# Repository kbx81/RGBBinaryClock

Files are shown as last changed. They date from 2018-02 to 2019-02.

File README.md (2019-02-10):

# kbx's RGB Binary Clock

RGB Binary Clock project files - PCB and source

_It's probably more than what you're thinking..._

## Another binary clock? Why?

I have to start by giving credit where credit is due. The
 [Boldport Club](http://boldport.club), over the last couple of years, has
 motivated me to dwell back into the world of electronics, at least as a
 hobbyist. Both the kits themselves and the other members in the club are
 amazing and helped inspire me to make something...so I began working on this
 project. Some inspiration is taken from
 [Touchy, BPC Project #7](https://www.boldport.com/products/touchy); this kit
 enabled me to learn more about and actually experiment with capacitive touch.
 It was clear early on that this would be a nice touch (pun intended) to add to
 this project; visually, it is cleaner, it reduces the number of parts and, as a
 result, it reduces the cost.

That said, the world probably doesn't need another (binary) clock. There are
 plenty of them--all different shapes and sizes--so why build another one?

This project was started with two main goals in mind: I wanted a "simple"
 project I could use to help me get back into the world of electronics. The
 second goal I had in mind was to build up my comfort level with C and C++ -- I
 knew the language(s) but was never terribly comfortable with them. Building
 this helped me to achieve both of those goals and then some -- and I am quite
 happy with the result!

_But why a clock?_

It's fun to make LEDs blink. It's fun to play with microcontrollers. It's fun
 to build stuff. But a blinking LED or two or three isn't very meaningful. Nor
 is a nice microcontroller that just toggles a GPIO pin. If you're going to
 build something, why not make it at least modestly useful? And why not build it
 in a unique way that's neat to look at and/or watch?

The idea for this came from an old electronics kit I put together probably
 around twenty or so years ago (and it still works today!). I liked the kit but
 it was somehow lacking. Probably the most obvious problem was that, in a dark
 bedroom, the display was too bright. It was a simple, 12-hour-only binary
 clock, built on 4000-series CMOS logic. Now, there's nothing wrong with that,
 but...it's 2018 now. Let's take it up a notch or ten.

## How do you take a binary clock up a notch (or ten)?

First, you can add some color. A lot of color. In fact, you can pick the colors
 you want it to use...up to eight times over. This binary clock has the ability
 to gradually shift colors over the course of each day. Bits can even fade in
 and out as they change. It's all about the eye candy in this regard.

Second, it can do more than just tell the time -- it'll tell you the date and
 temperature, too! There is even a timer/counter mode. What's more, you can
 choose the format for it all: the clock can display in a 12 or 24 hour format,
 the temperature can display in degrees Celsius or degrees Fahrenheit, and (most
 importantly) it can display all of these values in either binary-coded decimal
 (BCD) or good old-fashioned binary. You get to choose the formats you prefer
 and they can be changed easily at any time.

Next, the display brightness issue had to be addressed -- it has a
 phototransistor which is used to determine the amount of ambient light around
 it and the display will dim as the light level around it diminishes. This is
 great if you want to keep it near you at night while you sleep.

Another cool bit is that it uses capacitive sense touch keys for buttons; the
 kit it is based on had mechanical, fixed-function buttons. If you haven't seen
 or used capsense technology before, you'll find it's pretty cool and adds a
 little extra uniqueness to the clock, too.

A CR2032 coin-cell battery back-up can be installed to keep the time valid in
 the event that the board loses power. Version 4 of the hardware also includes a
 super capacitor, eliminating the need for the battery; even so, both can be
 installed, adding flexibility to the build.

Finally--and one could argue that no clock is complete without one--it has an
 alarm! The alarm can be set to beep at any of the eight times the user sets.
 There is also an hourly chime that one can enable which will beep out each hour
 in binary using high and/or low pitch tones...so you can hear the time when
 you're in another room! The display can be configured to blink when an alarm
 occurs. Version 4 of the clock also includes extra pin headers, some pins of
 which can be used as inputs to trigger the alarm from an external device.

## Great, but what makes it tick?

The "brain" is an STM32F072 microcontroller. This MCU alone has everything
 that's necessary to have a functional time clock -- even a temperature sensor
 as a bonus. Still, it might not be quite as accurate as some of us would like.
 For those folks, there are footprints for some additional ICs to improve the
 accuracy of the time and/or temperature sensing.

Version 2 boards have footprints for I2C devices:
* A Maxim DS3231
* An LM75 (or compatible)
* A Microchip MCP9808

Version 3+ boards have footprints for SPI devices:
* A Maxim DS3234
* An LM74
* A Maxim DS1722

Why footprints for both temperature sensors and the RTCs? The DS323x is somewhat
 expensive and it's possible that one might want more accurate temperature
 sensing abilities but isn't as concerned with the accuracy of the clock. It
 should be noted that the DS323x devices have temperature sensors built in and
 the application will use this sensor if a DS323x is installed but one of the
 other external temperature sensors is not.

Beyond the MCU itself, the board has 25 RGB LEDs on it; 24 of them form the main
 display and they are connected to TLC5947 (pre-v4) or TLC5951 (v4+)
 constant-current PWM drivers. The MCU uses its SPI1 to communicate with these
 drivers. The remaining RGB LED is used as a "status" LED and it is connected
 (through FET drivers) to GPIO pins on the MCU. These pins double as timer
 output channels, meaning they can also generate a PWM signal, enabling the
 dimming of the status LED elements, as well.

The beeper is connected (also through a FET driver) to yet another GPIO pin
 that doubles as a timer output channel; this enables the beeper to generate a
 wide range of tones or even play a tune!

The phototransistor is connected to the MCU's ADC channel zero.

Two USARTs are exposed via pin headers on the right side of the board: USART1
 is brought out on a standard six pin header as is commonly found on many
 devices while USART2 is connected to an RS-485 line driver enabling
 communication on an RS-485 bus. Through this interface, the application is able
 to receive a DMX-512 signal so the LEDs can each be individually controlled
 from an entertainment lighting console (or other application that speaks this
 protocol), enabling another whole realm of possibilities...

## How do I get or build one?

In this repository you'll find everything needed to put one together. It is
 divided into two major parts: hardware and software (source). The `hardware`
 directory contains the [KiCad](http://kicad.org) project files used to create
 the printed circuit board. The `src` directory contains the source code needed
 to compile and run the application on the microcontroller. It is built on top
 of [libopencm3](http://libopencm3.org). Finally, then `bin` directory contains
 compiled binary files you may flash directly onto the microcontroller...great
 for folks who want to solder something together but don't want to be bothered
 with compiling code!

Additional details regarding the hardware and software can be found in the
 `README.md` files located in each respective directory.

 **That's all for now...thanks for visiting!**

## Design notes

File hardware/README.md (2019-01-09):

# kbx's RGB Binary Clock

RGB Binary Clock PCB project files for KiCad (v4/v5)

## How do I get PCBs made for this?

Detailing the process is a bit outside of what I plan to discuss here. There are
 plenty of resources out around the web already that will do a better job of
 explaining this process than I can. That said, there's not much to it -- the
 files you need are here and all you need to do (more or less) is upload them
 to your PCB fabricator of choice and, after a few days, they'll ship them
 to you. I've used [OSHPark](http://oshpark.com) for the prototypes and I can
 assure you that they turn out fantastic (purple) boards.

As the vast majority of the components on this board are surface-mount parts,
 hot air is a fun approach for soldering it all together. If you go this route
 (and especially if you plan to build more than one of them), you'll likely want
 to have a stencil made to help with the placement of solder paste onto the
 board. I've used [OSHStencils](http://oshstencils.com) for this and they are
 very quick and do a wonderful job.

**Important**: The TLC5947 and TLC5951 LED driver ICs have a thermal relief (aka
 exposed) pad on their underside; this will not be possible to solder without a
 hot air soldering station or reflow oven. At low current/intensity levels, this
 shouldn't be a problem, but if you want your LEDs to be really bright, this
 could present an issue as the drivers will overheat quickly. Be careful!

## If I get boards made, how do I build it?

All the components are listed in the KiCad project files here; one can also find
 a bill of materials file named `kbxBinaryClock.bom.vX.csv` containing this
 list. For "unusual" parts (things that aren't resistors or capacitors) I've
 noted a suggested part number that should serve as a point of reference to help
 you find your own.

Before you order parts, be sure to read through the build notes below!

Once you have your boards and parts, there are at least a couple of different
 ways you can build the clock. Below are build notes.

## Build notes

### Before you begin...

...you need to determine:
1. Which version of the clock will you build? The answer should be "version 4"
 unless there is a specific reason you want/need an earlier version.
1. What will your time source be -- the STM32's RTC or the DS323x? The DS323x
 will provide the best accuracy. That said, these ICs add approximately $10 USD
 to the cost of the device. If you're purchasing them, be sure you're ordering
 the one that matches the version of the hardware you're planning on building!
1. What temperature sensor will you use -- the STM32's internal sensor, the
 DS323x's sensor, or a dedicated sensor? The DS1621/LM75/MCP9804/DS1722/LM74
 dedicated sensors will provide the best accuracy; however, if one of these ICs
 is not installed but a DS323x *is* installed, the app will use the DS323x's
 sensor. Note that, while the PCBs have footprints for more than one temperature
 sensor, only **one** of them may be installed at a time.
1. Solder-bridge/jumper settings. These are hardware version specific but *must*
 be set properly before you begin using the clock. More details are below...but
 don't forget about these!

Once you've settled on the items above, read on (below) for more detail and
 specifics regarding the build.

### Build details

#### External RTC:

The external RTC--the DS3231 (hardware version 2.x) or the DS3234 (hardware
 version 3.x+)--adds a level of precision to the clock that is likely difficult
 to achieve with the STM32's internal RTC alone. These RTC ICs are designed to
 drift less than two minutes _per year_. It's possible that your STM32 hardware
 could end up being this accurate, but it's more likely that it will not be.
 Install this IC if you want a clock that is as accurate as is reasonably
 possible. Note that this IC also has a built-in temperature sensor (that's part
 of how it maintains its precision) that the application will use if it is
 installed and the other external temperature sensor (below) is _not_ installed.

If you install a DS3231/DS3234 on your clock, **do not install**:
 - Hardware v2.x: `C6`, `R8`
 - Hardware v3.x: `C6`, `R19`
 - Hardware v4.x: `C5`, `R3`

#### External temperature sensors:
**U7 and U8 (all hardware versions)**

A challenge with using the STM32's internal temperature sensor is that the
 sensor typically reads a few degrees higher than the temperature around the
 MCU itself. This is because the die, where the sensor is located, is usually
 just a little bit warmer then the package around it. An easy workaround is to
 just subtract a few degrees from the reading -- hence the calibration item
 you'll find in the application's menu structure. It works, but it requires
 someone to tweak it as each chip is likely to be a little different. Naturally,
 this takes away from its accuracy.

Installing an external temperature sensor is a great solution to this problem.
 The application will prefer an external sensor if one is installed; it first
 prefers one of the dedicated temperature sensors. If not installed, it will try
 to use the sensor integrated into the DS323x, should one be installed. If these
 all fail, it will use the STM32's internal sensor as a last resort.

**IMPORTANT NOTE: the PCBs (all hardware versions) have footprints for two
 external temperature sensor ICs. ONLY INSTALL ONE of them. DO NOT INSTALL
 BOTH.** If you install both, neither of them will work and you may cause damage
 to them or to other ICs on the board.

#### RS-485 transceiver:
**U9** (hardware v2.x and v3.x)\
**U6** (hardware v4.x)

This part will enable the the second USART in the STM32 MCU to be used to
 communicate on an RS-485 bus. The original intention for this feature was to
 enable the device to receive a DMX-512 signal from an entertainment lighting
 console. With some development, it could also be used (for example) to
 synchronize a number of clocks with each other. This interface is more of a toy
 and has no impact on how the clock itself will function. You'll likely want to
 leave it off of the board unless you have a specific plan to use it for
 something.

#### Buzzer/beeper components:
**BZ1, D1, Q1, R1** (hardware v2.x and v3.x)\
**BZ1, D2, Q2, R19** (hardware v4.x)

If you don't want your clock to be able to make any noise at all, it is safe to
 leave these parts off of your board. It'll be sad, but it'll work just fine.

#### Current drive control components:
**Q6 through Q11, R21 through R24, R26 through R29, R31 through R34,
 R36 and R37** (hardware v2.x)\
**Q6 through Q11, R20 through R23, R25 through R28, R30 through R33,
 R35 and R36** (hardware v3.x)\
(Not applicable to hardware v4.x)

These parts enable some software control over the constant-current mechanism in
 the TLC5947 PWM drivers. They enable, in a sense, a "master dimmer" control
 over the display as a whole. Their state can be defined through one of the menu
 options within the application. While not implemented just yet, future software
 versions might exercise them automatically, such as when the ambient light
 level changes.

#### Status LED components:
**LED25, LED26, Q2 through Q4, R2 through R7** (hardware v2.x and v3.x)\
**LED25, LED26, Q3 through Q5, R20 through R22, R25 through R27** (hardware v4.x)

The status LED is not typically used during normal operation, however it can be
 enabled as an AM/PM indicator if/when the clock is set in 12-hour mode. It can
 also provide troubleshooting information if your clock doesn't seem to be
 working. That said, it's not necessary unless you like LEDs as much as I do.

#### Reset/Boot buttons:

The reset and boot buttons are of course not required, but it is convenient if
 you plan to do any development with this platform on your own.

### Other requirements

#### 32.768 kHz crystal installation and connection:

A footprint for a 32.768 kHz crystal exists on all of the PCBs. It is used to
 drive the STM32's internal RTC mechanism. This crystal is particularly
 important if the DS323x IC is **not** installed; in this case, it must be
 connected to the MCU by creating a solder bridge across the appropriate two
 pads on `SB1`. Failure to do so--and if the DS323x is not installed--means the
 clock won't run (although things otherwise may seem to work).

If the DS323x **is** installed, `SB1` may be bridged so as to connect the
 DS323x's 32.768 kHz signal output to the STM32's OSC32 input. This is not
 required but it is recommended so that this MCU input isn't left floating. In
 addition, if `SB1` is bridged in this manner, the 32.768 kHz crystal (and its
 drive capacitors) should **not** be installed.

#### Phototransistor series resistors:
 **Q5, RV1, R9 and R10** (hardware v2.x)\
 **Q5, RV1, R8 and R9** (hardware v3.x)\
 **Q1, RV1, R4 and R5** (hardware v4.x)

The phototransistor enables the application to determine the amount of ambient
 light around the clock so it can adjust the overall display intensity
 accordingly. There is a variable resistor in series with a fixed resistor which
 allows some manual adjustment over the sensitivity of this mechanism. There is
 also a single fixed resistor in parallel with this configuration. It is not
 necessary to install all of these, however it won't hurt anything if you do.
 If the specified phototransistor is used, a single 100K to 150K resistor
 installed on the larger component number's (`R5`, `R9` or `R10`, depending on
 your hardware version) pads will probably work well.

#### Status LED:

If installing a status LED, install only LED25 **or** LED26. Do not install
 both.

### Solder Bridge Jumpers

#### 32.768 kHz Oscillator jumper
**SB1**

This jumper determines if the 32.768 kHz oscillator or the DS323x's 32.768 kHz
 output pin is connected to the STM32's OSC32_IN pin. If a DS323x is **not**
 installed on the board, it must be bridged so that the crystal's pin is
 connected to the OSC32_IN pin. Otherwise, it's best to bridge it to the
 DS323x's 32.768 kHz output pin. It can be determined with a close look at the
 PCB which position is which.

#### Reset Supervisor jumper
**SB2** (hardware v2.x and v3.x)\
**SB4** (hardware v4.x)

This jumper determines if the DS323x's reset supervisor output pin is connected
 to the STM32's NRST (not-reset) pin. This should be connected if the DS323x is
 installed, however it sometimes causes issues with flashing the MCU. If you
 installed a DS323x and are having difficulty flashing the MCU, try
 disconnecting this jumper until the flashing process is complete. Don't forget
 to reconnect it, though!

#### USART 1/USB VBUS jumpers
**SB2, SB3** (hardware v4.x)

These jumpers are on version 4+ boards and allow some configuration of which
 USART1 pin on the MCU is connected to the six-pin serial header. Because the
 processor expects USB VBUS on PA9, if you plan to use the USB port, SB2 should
 be bridged and SB3 should be bridged to put PB6 on the on the six-pin header.
 If you do not want/need to use the USB port and wish to flash the MCU via the
 six-pin header, SB2 must be left **open** and SB3 should be bridged to put PA9
 on the six-pin header.

#### RS-485 Terminator jumper
**SB5** (hardware v4.x)

Bridge this jumper to connect the terminating resistor across the RS-485
 transceiver's input/output pins. This is useful if the board is at the end of
 a RS-485 link.

## Before powering it on for the first time...

WAIT! you didn't plug it in yet, did you? Let's do some pre-flight checks to get
 ready to bring up your board!

It's important that we go over the board with a DMM (or at least a continuity
 tester) and check for any nasty shorts. Solder bridges and poor part placement
 are the typical causes of this and it's not uncommon to have them, particularly
 with so many surface-mount parts. We don't want our brand-new clock to let out
 the magic smoke before we even get to use it, do we? :)

Generally, it will suffice to check a few key areas for shorts. Since these are
 surface-mount ICs, it's not uncommon to have solder bridges between some of the
 pins after you've soldered it all together. Don't worry, we can get away
 without checking _all_ of them, but we _do_ need to check a few. Let's make a
 list so we can check them off:
* **Check for shorts between the output of the LDO and ground.** Put one of your
 DMM probes on the power connector's ground pin and the other on the LDO's
 heatsink (the top fin soldered to the board -- this is its 3.3-volt output). If
 you see they're shorted, you'll have to go hunting for the short. Start by
 checking the power pins around the STM32 processor. All of its Vcc and ground
 pins are right next to each other so this is the best place to look first.
* **Check for shorts between the LED cathode pins and ground.** Again, put one
 of your DMM probes on the power connector's ground pin and drag the other probe
 across each of the pins of the LEDs (this also serves as a chance to check for
 a short directly across the power input -- touch any of the anode pins to do
 so). If there's a short, touch-up the pins on the TLC59xx drivers. It might
 even be necessary to lift the driver IC completely off of the board (you have a
 hot air soldering station, right?). Due to the exposed/thermal pad on the
 bottom of the TLC59xx LED drivers, it's possible to have a solder bridge
 between one of the LED pins and ground. If this happens, the affected LED(s)
 will pop/fry/smoke/burn out immediately upon applying power to the board.
* **Check for shorts between the TLC59xx IREF pin and ground.** These pins are
 also adjacent and, if IREF is shorted to ground, too much current will flow
 through the LEDs (they'll be super bright and burn out quickly). This situation
 also increases the power dissipation of the TLC59xx drivers so they'll heat up
 unnecessarily. This also affects the power draw on the LDO so it'll get
 unnecessarily hot, too!
* **Check that the solder bridge "jumpers" are set correctly.** You didn't
 forget to bridge these as appropriate, did you? :) See the "Jumpers" section
 above for information on how they should be set.

Once you've confirmed everything above looks good, it should be reasonably safe
 to proceed to the next step -- flashing the firmware onto the STM32 processor!
 After we do this, we'll be able to more effectively identify any other
 soldering-related issues that could be affecting the clock's operation.

After you power on your board for the first time--and if nothing blows
 up--you'll need to flash the firmware onto the STM32 MCU. Hardware version 4.x
 of the clock also has a USB interface that may be used for this purpose, in
 addition to the SWD connection (P1/P2) or the serial interface on J2/J4. Either
 way, you'll need an appropriate adapter to do so. You can find the source,
 compiled binary files and flashing instructions in the `src` folder one level
 up in the repo's hierarchy. With the right tools in hand, this can be done in a
 couple of minutes.

If you're having trouble flashing the MCU, please see the next section.

## Troubleshooting

What's that? You couldn't flash the MCU? Or maybe it isn't working perfectly
 after you flashed the MCU? Uh oh...

As I've built...a few...of these to date, here is a list of common issues I've
 stumbled across as well as some notes on how to fix them.

If you're having trouble flashing the MCU, check these items first:
* If a DS323x is installed, is the reset supervisor jumper bridged? If so, this
 may be holding the STM32 in a reset state too long and your programmer is
 giving up. Open this jumper and try again.
* If there is no DS323x installed and/or the jumper is already open, check the
 data lines  between the port you're using (six-pin serial, USB, or SWD) and the
 processor. Perhaps there is another nasty solder bridge somewhere that's
 shorting one or more of the lines to Vcc, ground, or another adjacent pin. If
 you're using the USB interface on a version 4+ board, take a close look at D1
 and the physical USB port itself, as well.

If you flashed the MCU and it's now doing...something...but it doesn't seem
 right, here are some more common symptoms and how to fix them:

* **Status LED blinks white/gray but the main display is blank or flickers
 erratically.** This is indicative of some soldering problem on the SPI1 pins
 of the MCU or on one or more of the TLC59xx drivers. Take a close look at these
 pins and rework them as necessary.
* **One or more of the touch keys don't work.** Check the 1K resistors that sit
 between the touch keys and the MCU as well as the 47 nF sense capacitors.
 Again, also check the relevant pins on the MCU itself for shorts to adjacent
 pins.
* **It keeps making a ticking sound.** There's a problem with one or more of the
 touch keys -- see the item above.
* **The status LED alternates red and yellow.** You did not install a DS323x (or
 maybe you did and it's not working) and the STM32's RTC/LSE oscillator did not
 start within the expected amount of time. Check that `SB1` is bridged correctly
 and that the 32.768 kHz crystal and its bypass capacitors are installed and
 soldered correctly.
* **One or more of the LEDs are weird/mismatched colors.** This indicates that
 one or more of the LED pins on the TLC59xx drivers aren't soldered well. It
 could also mean that you have (a) bad LED(s) (maybe you overheated them or
 heated them for too long while soldering). Rework the relevant pins on the
 TLC59xx ICs and (hopefully) your LEDs will look normal afterwards. If not, you
 may want to try swapping out the affected LED(s).
* **One or more blocks of LEDs is brighter than the other block(s) of LEDs
 and/or one or more of the TLC59xx drivers is HOT along with the LDO.** Check
 the IREF pin on the (hot) driver below the block of LEDs that appears to be
 brighter than the others. It's probably shorted to ground.

## Known Issues and Noteworthy Items

You may have noticed the "hefty" 2-amp power supply rating on the board. Why is
 it so big? Well, each LED is rated for 20 milliamps (mA)...but are three colors
 per physical LED, adding up to 60 mA each. Then there are 25 LEDs...which adds
 up to 1500 mA -- a lot of current! We need a little extra for the other parts
 of the clock, so a 2 amp supply covers that nicely. That said, under normal use
 as a clock, it's unlikely that *all* of the LEDs would ever be fully on and
 driven at a full 20 mA each; in this case, you can likely get away with a power
 supply with a lesser rating. Under DMX-512 (or some other) control, however, it
 is possible that this situation could occur, so the goal was to ensure that the
 board could handle it. With that in mind, however, **if you wish to drive all
 of the LEDs at their full rated current of 20 mA for more than a few seconds at
 a time, you need to ensure three things happen:**
* The exposed pad on the LED driver ICs must be properly soldered to the PCB
* Heatsinks should be glued (with appropriate thermal epoxy) to the driver ICs
* The PCB should be manufactured with a 2 oz copper weight

Damage to your board and/or the parts on it may occur if the heat is not
 sufficiently dealt with -- the drivers can become VERY HOT!

Speaking of heat, said heat from the LED drivers can skew the temperature
 reading from the sensor on the board. This becomes more noticeable as the LEDs
 become brighter. Version 4.x of the PCBs includes footprints for additional
 2.54mm pin headers which could be used for mounting the temperature sensor(s)
 off of the main board.

Due to the nature of how the TLC5947 drivers work, frequent display refreshes
 (such as when LEDs are fading between colors and/or intensities) sometimes
 cause some faint flickering or pulsing of the LEDs. Version 4.x of the hardware
 resolves this issue by using TLC5951 drivers. These have a clock input to the
 PWM engine enabling writes to the data latches to be synchronized with PWM
 cycles. The result is smooth fading of the LEDs at all intensities with some
 additional benefits, as well!

## Legal stuff and License

The circuit schematics and PCBs found here are licensed under the
 [Creative Commons Attribution-ShareAlike 4.0 International License](http://creativecommons.org/licenses/by-sa/4.0/).



_Happy building!_

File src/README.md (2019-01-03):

# kbx's RGB Binary Clock

RGB Binary Clock firmware source files

## What's going on here?

Here you will find the C++ source code files for the RGB Binary Clock. It is
 modularized so that its various parts can be broken out and potentially re-used
 for other projects. It's not perfect but it works well and the plan is to
 continue to update and improve it over time.

The firmware implements all of the clock's functionality from the simple display
 of the time and date through color selection and management, alarms, and even
 DMX-512 control for the display LEDs. It could be easily modified to provide a
 variety of other capabilities if desired.

## More specifics

The code is written for the STM32F072 microcontroller used on the RGB Binary
 clock. With a little effort, it should be relatively easy to port it to another
 STM32Fx-series MCU. It relies on [libopencm3](http://libopencm3.org) as the
 underlying platform to interface with the MCU. If you wish to do some hacking
 with this platform, a nice guide can be found
 [here](https://github.com/libopencm3/libopencm3-examples#reuse) which explains
 how to clone libopencm3 for (re)use within your own (or this) project. Note
 that if you do so, it may be necessary to tweak some paths in the Makefile(s),
 but otherwise things should work without much trouble. You'll also (of course)
 need a (gcc) compiler to build the code base. (At the time of this writing,
 I've been building it with gcc on macOS Mojave and High Sierra.)

The STM32F072 microcontroller is a rich device with a lot of peripherals. Many
 of these peripherals are leveraged in the code to enable it work as efficiently
 as possible. For posterity, here is a list of the peripherals used:

* ADC - the analog to digital converter, used for sensing light level from the
  attached phototransistor
* CRC - used to compute a checksum for settings data stored in FLASH
* DMA - direct memory access controller, used to speedily move data to/from
  other I/O peripherals such as I2C, SPI, and USARTs
* FLASH controller - erases and writes settings to a dedicated block of FLASH so
  settings are retained across power failures and do not depend on the battery
* GPIO - because how else do you toggle pins on/off or read input signals?
* I2C - interfaces with the DS3231 and temperature sensor on pre-v3 boards
* IWDG - the watchdog timer makes sure the MCU gets reset in the event of some
  catastrophic software crash/failure
* NVIC - none of this would be possible without interrupts.
* RTC - the real time clock is used if the DS323x is not installed. Since it's a
  clock, you need a clock...sooooo...
* SPI - this is the interface (via DMA) to the display/LED driver ICs. On v3+
  boards, it is also the interface to the DS3234 and other temperature sensors.
* Timers - Timers 1 and 2 are used to generate PWM for the status LEDs and for
  the buzzer. Timers 15 and 16 are used to supervise DMX-512 communication.
* TSC - the touch sensing controller is used to sense touches on the touch keys.
* USARTs - USART1 is a general serial interface and USART2 is connected to an
  RS-485 transceiver. This firmware enables a DMX-512 signal to be received on
  USART2 so that the LEDs can be individually controlled remotely.

## Important!
As of 2018-12-20, the source code has been consolidated into a single tree. When
 compiling (with gcc), you'll need to add `-DHARDWARE_VERSION=X` to the command
 line, where `X` is the major version number of the hardware you're targeting.
 Note that this switch has already been added to the included Makefile. In
 general, the consolidated sources will make maintaining the code base easier
 moving forward, albeit at the expense of some extra bloat in some of the source
 files. Be aware of this if you choose to build it yourself and/or do some hacking!

## I want to hack. Where do I start?

`RGBBinaryClock.cpp` is where it all begins. This connects the various
 interrupts to the appropriate functions for processing them, initializes the
 hardware, initializes the main application, then passes control to the main
 application loop. See `Application.cpp` and `Hardware.cpp` and work your way
 through the rest from there.

Please don't hesitate to reach out with any questions or comments -- it is nice
 to hear feedback. Happy hacking!

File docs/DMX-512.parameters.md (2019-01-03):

# kbx's RGB Binary Clock

This document summarizes how DMX-512 channels may be used to control the clock's
 display LEDs and beeper.

## RGB Binary Clock DMX-512 parameter list

### Standard mode
* Channel 1: Master intensity
  * 0%: Shut (blackout)
  * 1%-100%: Dim -> Bright
* Channel 2: LED1 Red level
* Channel 3: LED1 Green level
* Channel 4: LED1 Blue level
*  ...
* Channel 71: LED24 Red level
* Channel 72: LED24 Green level
* Channel 73: LED24 Blue level
* Channel 74: LED25 (status) Red level
* Channel 75: LED25 (status) Green level
* Channel 76: LED25 (status) Blue level

### Extended mode
* Channel 1: Display control
  * 0%-12%: Display DMX-512 per-pixel (as below)
  * 13%-24%: Display time
  * 25%-36%: Display date
  * 37%-48%: Display temperature
  * 49%-60%: Display timer/counter (stop)
  * 61%-72%: Display timer/counter (run/count up)
  * 73%-84%: Display timer/counter (run/count down)
  * 85%-100%: Display timer/counter (reset)
* Channel 2: Beeper volume control
  * 0%: Beeper/tone off/muted
  * 1%-100%: Beeper volume low -> high
* Channel 3: Beeper pitch/tone control
  * 0%-100%: Beeper pitch/tone low -> high
* Channel 4: Display Strobe
  * 0%: Strobing off/display normal
  * 1%-100%: Strobe fast -> strobe slow
* Channel 5: Fade rate
  * 0%-100%: Fade fast -> fade slow
* Channel 6: Master intensity
  * 0%: Shut (blackout)
  * 1%-100%: Dim -> Bright
* Channel 7: LED1 Red level
* Channel 8: LED1 Green level
* Channel 9: LED1 Blue level
*  ...
* Channel 76: LED24 Red level
* Channel 77: LED24 Green level
* Channel 78: LED24 Blue level
* Channel 79: LED25 (status) Red level
* Channel 80: LED25 (status) Green level
* Channel 81: LED25 (status) Blue level

In Extended mode when displaying time, date, temperature, or timer/counter,
 LEDs 1 and 2 become the display's 0 and 1 colors, respectively.

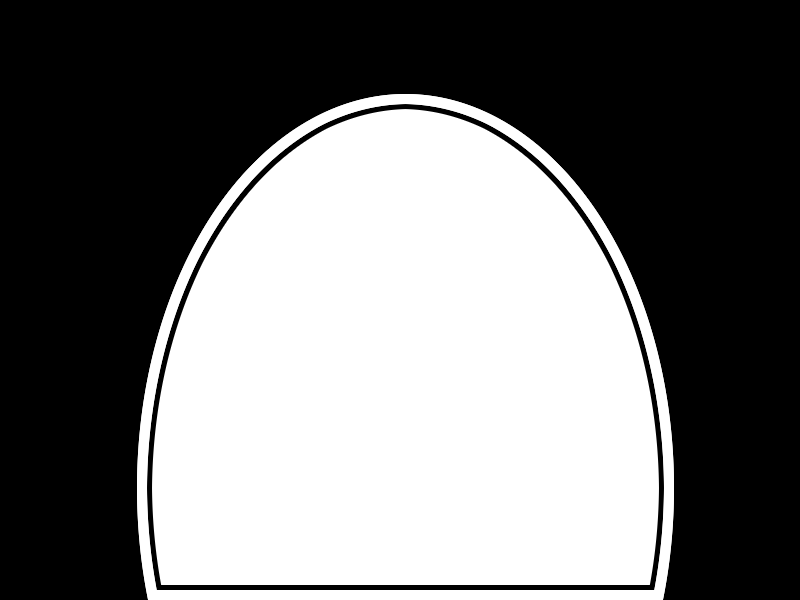
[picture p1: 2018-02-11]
hardware/touchbutton.png

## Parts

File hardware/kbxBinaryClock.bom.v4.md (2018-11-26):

Reference | Qty | Value | Footprint | Description/Documentation/Vendor
--------- | --- | ----- | --------- | --------------------------------
BT1 | 1 | CR2032 | Battery_Holders:Keystone_103_1x20mm-CoinCell | [Battery cell](http://www.keyelco.com/product.cfm/product_id/719)
BZ1 | 1 | Buzzer | Buzzers_Beepers:Buzzer_12x9.5RM7.6 | [Buzzer, polar](https://product.tdk.com/en/search/sw_piezo/sw_piezo/em-buzzer/info?part_no=SD1614TT-B1)
C1, C2 | 2 | 10 pF | Capacitors_SMD:C_0805 | Unpolarized capacitor
C3, C4 | 2 | 12.5 pF | Capacitors_SMD:C_0805 | Unpolarized capacitor
C5**, C8, C10, C11, C12, C16, C17, C18, C19, C20, C22, C21, C24, C27 | 14 | 100 nF | Capacitors_SMD:C_0805 | Unpolarized capacitor
C6 | 1 | 10 nF | Capacitors_SMD:C_0805 | Unpolarized capacitor
C7 | 1 | 1 µF | Capacitors_SMD:C_0805 | Unpolarized capacitor
C9, C13 | 2 | 4.7 µF | Capacitors_SMD:C_0805 | Unpolarized capacitor
C14, C15 | 2 | 47 nF | Capacitors_SMD:C_0805 | Unpolarized capacitor
C23 | 1 | 100 µF | Capacitors_SMD:CP_Elec_8x10 | [Polarized capacitor](https://industrial.panasonic.com/ww/products/capacitors/polymer-capacitors/os-con/svf/25SVF100M)
C25 | 1 | 10 µF | Capacitors_SMD:C_0805 | Unpolarized capacitor
C26 | 1 | 470 mF | kbxCustoms:CP_Radial_D13.0mm_P5.00mm_HD1.5mm | [Polarised capacitor](http://www.cooperindustries.com/content/dam/public/bussmann/Electronics/Resources/product-datasheets/Bus_Elx_DS_4327_KR_Series.pdf)
D1 | 1 | USBLC6 | TO_SOT_Packages_SMD:SOT-23-6 | [TVS Diode/Array](https://www.st.com/resource/en/datasheet/usblc6-2.pdf)
D2 | 1 | 1N4148 | Diodes_SMD:D_SOD-123 | [Diode](https://www.diodes.com/assets/Datasheets/ds30086.pdf)
D3 | 1 | S3A | Diodes_SMD:D_SMC | [Diode](http://www.onsemi.com/pub/Collateral/S3N-D.PDF)
D4 | 1 | BAT64-04 | TO_SOT_Packages_SMD:SOT-23 | [Dual diode](https://www.infineon.com/dgdl/Infineon-BAT64SERIES-DS-v01_01-en.pdf?fileId=db3a304314dca3890115191757980ead)
D5 | 1 | BAT64-02V | Diodes_SMD:D_0603 | [Diode](https://www.infineon.com/dgdl/Infineon-BAT64SERIES-DS-v01_01-en.pdf?fileId=db3a304314dca3890115191757980ead)
F1 | 1 | ~2A Polyfuse | Fuse_Holders_and_Fuses:Fuse_SMD2920 | [Resettable fuse, polymeric positive temperature coefficient (PPTC)](http://m.littelfuse.com/~/media/electronics/datasheets/resettable_ptcs/littelfuse_ptc_2920l_datasheet.pdf.pdf)
J1 | 1 | Conn_02x08_Odd_Even | Pin_Headers:Pin_Header_Straight_2x08_Pitch2.54mm | Generic connector, double row, 02x08
J2 | 1 | Conn_02x05_Odd_Even | Pin_Headers:Pin_Header_Straight_2x05_Pitch2.54mm | Generic connector, double row, 02x05
J3 | 1 | Conn_02x03_Odd_Even | Pin_Headers:Pin_Header_Straight_2x03_Pitch2.54mm | Generic connector, double row, 02x03
J4 | 1 | Conn_01x06 | Pin_Headers:Pin_Header_Straight_1x06_Pitch2.54mm | Generic connector, single row, 01x06
J5 | 1 | Jack-DC | BARREL_JACK | DC_Barrel Jack
LED1 through LED25 | 25 | LED_RGB_COMMON_ANODE | LEDs:LED_D5.0mm-4 | [RGB LED](https://www.adafruit.com/product/302)
LED26 | 1 | LED_Dual_AACC | LEDs:LED_Cree-PLCC4_3.2x2.8mm_CCW | [LED, dual color, 4-pin](https://www.vcclite.com/product/led-smt-1206-1-72-1v-20ma-redgreen-2k/)
P1 | 1 | CONN_MICRO_USB_B | Connectors_USB:USB_Micro-B_Molex-105017-0001 | [Micro-USB-B](https://www.molex.com/webdocs/datasheets/pdf/en-us/1050170001_IO_CONNECTORS.pdf)
P2 | 1 | STM32_SWD_USART | Pin_Headers:Pin_Header_Straight_2x05_Pitch1.27mm_SMD | [Header](https://www.harwin.com/products/M50-3600542R/)
Q1 | 1 | Q_Photo_NPN | LEDs:LED_D5.0mm | [Phototransistor NPN, 2-pin (C=1, E=2)](https://www.vishay.com/docs/84768/tept5600.pdf)
Q2, Q3, Q4, Q5 | 4 | 2N7002 | TO_SOT_Packages_SMD:SOT-23 | [50V Vds, 0.22 A Id, N-channel MOSFET, SOT-23](https://www.diodes.com/assets/Datasheets/ds11303.pdf)
R1 | 1 | 47K | Resistors_SMD:R_0805 | Resistor
R2 | 1 | 68K | Resistors_SMD:R_0805 | Resistor
R5, R19, R25, R26, R27 | 5 | 1M | Resistors_SMD:R_0805 | Resistor
R3**, R4, R6, R7, R8, R18***, R23, R24 | 8 | 10K | Resistors_SMD:R_0805 | Resistor
R9, R10, R11, R12, R13, R14, R20*, R21*, R22* | 9 | 1K | Resistors_SMD:R_0805 | Resistor
R15*, R16*, R17* | 3 | 2K7 | Resistors_SMD:R_0805 | Resistor
R28 | 1 | 0 | Resistors_SMD:R_0805 | Resistor
R29 | 1 | 120 | Resistors_SMD:R_0805 | Resistor
R30 | 1 | 56 0.5W | Resistors_SMD:R_0805 | [Resistor](https://industrial.panasonic.com/cdbs/www-data/pdf/RDO0000/RDO0000C337.pdf)
RV1 | 1 | 100K | Potentiometers:Potentiometer_Trimmer_Vishay_TS53YJ | [Potentiometer](http://www.bourns.com/docs/Product-Datasheets/TC33.PDF)
SW1, SW2 | 2 | SW_Push | Buttons_Switches_SMD:SW_SPST_KMR2 | [Push button switch, generic, two pins](https://www.ckswitches.com/media/1479/kmr2.pdf)
U1 | 1 | STM32F072RBTx | Housings_QFP:LQFP-64_10x10mm_Pitch0.5mm | [ARM Cortex-M0 Package: LQFP64 Flash: 128KB Ram: 16KB Frequency: 48MHz](http://www.st.com/content/ccc/resource/technical/document/datasheet/cd/46/43/83/22/d3/40/c8/DM00090510.pdf/files/DM00090510.pdf/jcr:content/translations/en.DM0009051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)
U2, U3, U4 | 3 | TLC5951 | kbxCustoms:HTSSOP-38_6.1x12.5mm_Pitch0.65mm_ThermalPad | [LED Driver](http://www.ti.com/lit/ds/symlink/tlc5951.pdf)
U5 | 1 | DS3234 | Housings_SOIC:SO-20_12.8x7.5mm_Pitch1.27mm | [DS3234 SPI Bus Real-time Clock with Integrated Crystal](https://datasheets.maximintegrated.com/en/ds/DS3234.pdf)
U6 | 1 | MAX485E | Housings_SOIC:SOIC-8_3.9x4.9mm_Pitch1.27mm | [Half duplex RS-485/RS-422, 2.5 Mbps, �15kV electro-static discharge (ESD) protection](http://www.st.com/content/ccc/resource/technical/document/datasheet/81/93/fa/ed/87/47/46/00/CD00003136.pdf/files/CD00003136.pdf/jcr:content/translations/en.CD0000313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)
U7 | 1 | DS1722 | Housings_SOIC:SOIC-8_3.9x4.9mm_Pitch1.27mm | [Temperature Sensor](https://datasheets.maximintegrated.com/en/ds/DS1722.pdf)
U8 | 1 | LM74 | Housings_SOIC:SOIC-8_3.9x4.9mm_Pitch1.27mm | [Temperature Sensor](http://www.ti.com/lit/ds/symlink/lm74.pdf)
U9 | 1 | LD1117S33TR | TO_SOT_Packages_SMD:TO-252-2 | [1A Low Dropout regulator, positive, 1.5V fixed output, SOT-223](http://www.st.com/content/ccc/resource/technical/document/datasheet/a5/c3/3f/c9/2b/15/40/49/CD00002116.pdf/files/CD00002116.pdf/jcr:content/translations/en.CD0000211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)
Y1 | 1 | 8 MHz | Crystals:Crystal_SMD_5032-4pin_5.0x3.2mm | [Two pin crystal](http://www.abracon.com/Resonators/abm3b.pdf)
Y2 | 1 | 32.768 KHz | Crystals:Crystal_SMD_3215-2pin_3.2x1.5mm | [Two pin crystal](https://www.ecsxtal.com/store/pdf/ECX-.327-CDX-1293.pdf)

* = These resistor values may require adjustment based on LED current requirements. As specified, they will work with the aforementioned RGB LEDs with a 9-volt supply.
** = Do not install if DS3234 is installed
*** = Not required

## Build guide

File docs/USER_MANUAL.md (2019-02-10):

# kbx's RGB Binary Clock

_So...I built one (or someone gave me one), loaded the firmware and...now what?_

Congratulations! Read on...

## Getting started with your RGB Binary Clock

After confirming everything is working, using the clock is pretty simple! Here's
 how it works:

When powered on, the clock is either set or it is not set (such as if the
 battery/capacitor drained or this is the first time you've powered it on).
* If the clock is set, it will resume displaying the time (and date and
  temperature, if the "Default to Toggle mode" option is enabled. More on this
  later on).
* If the clock is not set, the least-significant bits will blink at .5 Hz
  in white on a dark-gray "background".

If you see the latter (flashing LSbs), you'll need to set the time and date!
 But before we do that...

### How do I read the display?

The main display consists of 24 RGB LEDs; there is also a "status" RGB LED.
 You'll quickly notice that the display is divided into three "blocks". For the
 sake of this guide, let's refer to them like this:
```
X T  P L  H D
W S  O K  G C
V R  N J  F B
U Q  M I  E A
```

#### For the experienced binary enthusiast

In BCD mode:
```
D, H, L, P, T, X = 8 (2^3) MSbs, top row
C, G, K, O, S, W = 4 (2^2)
B, F, J, N, R, V = 2 (2^1)
A, E, I, M, Q, U = 1 (2^0) LSbs, bottom row
```
In binary mode:
```
H, P, X = 128 (2^7) MSbs
G, O, W = 64  (2^6)
F, N, V = 32  (2^5)
E, M, U = 16  (2^4)
D, L, X = 8   (2^3)
C, K, S = 4   (2^2)
B, J, R = 2   (2^1)
A, I, Q = 1   (2^0) LSbs
```

You're all set! Skip to the next section to begin learning how to use the clock.

#### The longer explanation...

As with a not-binary clock, the display shows you numbers. Hours, minutes, and
 seconds...or year, month, day (see footnote below)...you get the idea and
 (hopefully) are starting to see the connection. That said, how do we read this
 one?

The clock has the ability to display numbers in two different ways: in binary,
 or in binary-coded decimal (BCD, which is the default). (Which format it uses
 can be easily changed at any time -- more on this later.) It is very important
 to distinguish between them as it directly affects how information on the
 display is interpreted.

Since it is the default, let's discuss the BCD mode first. In BCD mode, we're
 looking at decimal numbers (0 through 9) encoded in binary. That is, for each
 column of LEDs in the display, possible values are 0 to 9. As there are six
 columns, and because of the "decimal" part in "binary-coded decimal" we have
 (from left to right) tens of hours/years (U-X), ones of hours/years (Q-T), tens
 of minutes/months (M-P), ones of minutes/months (I-L), tens of seconds/days
 (E-H), ones of seconds/days (A-D). With these identified, all we have left is
 to identify the binary place values -- take a look at the table above.

In the binary display mode, each of the three "blocks" of LEDs forms a single
 byte. Since a byte consists of eight bits, and because each bit can be either a
 one or a zero, we have 2^8 or 256 possible values we can display in each block
 of LEDs, which translates to values from 0 to 255. This works out perfectly if
 we consider what the clock displays -- hours, minutes, seconds, years, months,
 days, and (room) temperature (whether degrees C or degrees F). None of these
 values dwell outside of the range of 0 to 255 (well, assuming we display the
 year as two digits). That said, each block of LEDs (A-H, I-P, Q-X) corresponds
 directly to the eight bits in a byte. The "lowest" letter (A, I, Q) in each
 block is the least-significant bit and the "highest" letter (H, P, X) in each
 block is the most-significant bit. See the table above for their exact place
 values.

If at this point you're thinking "I'm lost", you'll want to do some additional
 reading/research ([Google](http://google.com) is your friend) on the binary
 number system -- it's a bit out of scope for this document but will prove
 helpful (even necessary) as we move forward.

### I can read it! Now what?

If you've powered it on and are looking at blinking LSb and status LEDs, you'll
 first need to set the time and date. To do so, start by touching the `E` touch
 key. This will exit the time/date/temperature view and enter into the main menu
 view.

#### The Main Menu view

You can identify the main menu view as you'll see white-on-gray LEDs
 (these are the default colors, although they can be changed -- more on this
 later) with the selected menu item number displayed on the left-most block of
 LEDs. Press the `U` key to increase or the `D` key to decrease the selected
 menu item number as indicated by the LEDs. To make your selection, touch the
 `E` key again to enter into the selected mode/menu item. (Perhaps you are
 starting to build the connection that `E` means "Enter"/"Exit".)

#### Setting the time and date

If, when you started, the time and date were not set, entering the main menu
 view will automatically select option 5, the "set time" function. If option 5
 is not selected, use the `U` and/or `D` keys to select it. Touch the `E` key to
 enter into the set time/date view to set the time.

Once you've entered into mode 5, you'll see the set time/date view. This is the
 standard view used to set times and dates. By default, the display uses green
 for bits with a value of `0` and red for bits with a value of `1` (although,
 again, these colors can be changed -- more on this later). In this view, the
 touch keys work as follows:

* `U` increases the selected value
* `D` decreases the selected value
* `C` moves the selection left
* `B` moves the selection right
* `A` applies the date/time as set
* `E` exits to the main menu

Use the keys to adjust the values to the correct time and touch the `A` key to
 commit the time shown on the display to the clock's hardware. When you're done,
 touch the `E` key to exit back to the main menu.

**Important:** You must touch the `A` key to save the time/date as set! If you
 do not, the selected values will be lost upon exiting the set time/date view.

Once the time has been set, the date must be set. Upon exiting mode 5 (set
 time), mode 6 will be automatically selected if the date has not been set
 (that is, if the year is equal to zero, which...yeah...). In any event, mode 6
 is the "set date" mode and, once it is selected in the main menu, touch the `E`
 key again to enter that mode to set the date.

Setting the date works exactly the same way as setting the time does in terms of
 the user interface. Note that, by default, the display shows **year**,
 **month**, **day** (see footnote below). Use the keys as described above to
 make the appropriate selections and then press the `A` key to apply them. The
 `E` key exits back to the main menu view.

 #### I set my clock! What's next?

 Congratulations! You've now got a working, set clock! At this point, use the
  main menu to select either mode 1 (fixed time/date/temperature display) or
  mode 2 (auto-toggle time/date/temperature displays) to see the time, date,
  and/or temperature.

At this point, we're left with...

## Advanced topics and settings

Your RGB Binary Clock can do more than just show you the time, date, and
 temperature in binary or BCD. Let's dig in and take a closer look!

### Views

The RGB Binary Clock has a number of configuration options that may be changed,
 allowing some customization of the clock's behavior. If you've just gone
 through the process of setting the time and date, you've already begun using
 some of its simple menu system and "views".

Configuration options/settings are changed by using a number of different views.
 These views provide a way to access the various settings so that they may be
 modified. Each setting is really nothing more than a number, but this number
 determines something: the volume of the beeper, the intensity of a color on the
 display, or the hour in which DST takes effect, as some examples. The various
 views simply display this information in a way that makes sense while providing
 a means by which to modify the settings.

Entering into any given mode activates a view. Each view presents information on
 the display a little differently. In addition, the touch keys are used somewhat
 differently in each view. Let's describe the views now, as, later on when we
 discuss the various modes, we'll refer back to the views to describe the
 expected behavior (what you'll see on the display, what the touch keys will do,
 etc.) upon entering into any given mode.

#### Main Menu View

If you've gone through the process to set the time and date, you've already seen
 this view. You can identify the main menu view as you'll see (by default, at
 least) white-on-gray LEDs with the selected menu item number displayed on the
 left-most block of LEDs. The touch keys are used as follows:
* `U` increases the selected mode number
* `D` decreases the selected mode number
* `C` enters Time/Date/Temperature view in toggle mode (aka mode 2)
* `B` enters Time/Date/Temperature view in fixed mode (aka mode 1)
* `E` enters into the selected mode

#### Time/Date/Temperature View

This is the view that--you guessed it--displays the time, date, and temperature.
 This same view is used whether the clock is in mode 1 (fixed display) or mode 2
 (toggle/rotate display). This is the view in which your RGB Binary Clock will
 spend the vast majority of its time. In this view, the touch keys are used as
 follows:
* `U` increases the display intensity (if automatic adjustments are disabled)
* `D` decreases the display intensity (if automatic adjustments are disabled)
* `C` displays the temperature
* `B` displays the date
* `A` toggles display of time (hours, minutes, seconds) and seconds-since-midnight
* `E` exits to the main menu

#### Timer/Counter View

This is the view that displays the timer/counter. In this view, the touch keys
 work as follows:
* When the timer/counter is stopped:
  * `U` increases the timer/counter value
  * `D` decreases the timer/counter value
* When the timer/counter is running:
  * `U` counts up at next start
  * `D` counts down at next start
* `C` resets the timer/counter
* `B` stops the timer/counter
* `A` starts the timer/counter
* `E` exits to the main menu

#### DMX-512 View

This view displays data being sent to the clock via DMX-512. If no DMX-512
 signal is present on the RS-485 serial interface, this view does nothing and
 will not activate. See the DMX-512 parameters document for more information.

#### Set Time/Date View

If you've already set your clock, you've seen this view; it was also described
 above. This is the view used to set times and dates. By default, the display
 uses green for bits with a value of `0` and red for bits with a value of `1`.
 The existing values are shown when the view is entered. One block of LEDs will
 be "highlighted" at a time and the value on the highlighted block is what will
 be modified by the `U` and `D` touch keys. In this view, the touch keys work as
 follows:
* `U` increases the selected value
* `D` decreases the selected value
* `C` moves the selection left
* `B` moves the selection right
* `A` applies the date/time as set
* `E` exits to the main menu

#### Set Bits View

This view is used to modify settings that are either on/enabled/`1` or
 off/disabled/`0`. By default, the display uses green for bits with a value of
 `0` and red for bits with a value of `1`. The existing settings are shown when
 the view is entered. One LED will be "highlighted" at a time. The touch keys
 can be used to toggle the various settings on and off as follows:
* `U` selects the next bit
* `D` selects the previous bit
* `C` sets/turns on the bit
* `B` clears/turns off the bit
* `A` applies (saves) the settings
* `E` exits to the main menu

#### Set Value View

This view allows adjusting of various settings values. The existing value is
 shown when the view is entered and it appears on the right side of the display.
 By default, the display uses green for bits with a value of `0` and red for
 bits with a value of `1`. The touch keys work as follows:
* `U` increases the displayed value
* `D` decreases the displayed value
* `C` sets the displayed value to the maximum allowed value for the setting
* `B` sets the displayed value to the minimum allowed value for the setting
* `A` applies (saves) the selected value
* `E` exits to the main menu

#### Set Colors View

Any given color as it appears on the RGB LEDs consists of a mix of red, green,
 and blue elements. As bits have two possible states (`0` or `1`), each color
 setting that the RGB Binary Clock stores consists of two colors -- one for `0`
 bits and one for `1` bits.

This view is used to modify the color settings for the RGB Binary Clock's
 various displays/views. It allows the modification of two colors
 simultaneously: the `0` color and the `1` color. The display is divided into
 two parts: the left and center LED blocks display the current value of the
 selected color element and the right block of LEDs displays a preview of the
 resulting colors based on the red, green, and blue values chosen.

On the left and center LED blocks, you'll see one of seven possible displays:
1. Red on Gray (`1` color)
1. Green on Gray (`1` color)
1. Blue on Gray (`1` color)
1. White on Red (`0` color)
1. White on Green (`0` color)
1. White on Blue (`0` color)
1. White on Gray (increment)

Items 1 through 3 indicate that the `1` color (red, green, or blue) is selected
 for adjustment; items 4 through 6 indicate that the `0` color is selected for
 adjustment. The last item indicates the current value of the increment to be
 used as any given color is adjusted; it appears when the `B` key is touched.
 When the `U`, `D`, or `C` keys are touched, the display will revert back to the
 selected color element (one of items 1 through 6 above).

To summarize, the touch keys work as follows:
* `U` increases the selected color value by the selected increment
* `D` decreases the selected color value by the selected increment
* `C` changes the selected color element (see items 1 through 6 above)
* `B` changes the selected increment (1, 16, or 256)
* `A` applies (saves) the selected value
* `E` exits to the main menu

### Time Slots

The RGB Binary Clock has the ability to store up to eight "times of
 significance" -- you can think of it as an alarm clock with eight different
 alarm times that you can set. Moving forward, we'll refer to each of these
 times as a "time slot".

Each of these eight time slots can be configured to trigger any (combination) of
 three events:
1. An audible alarm
1. A blinking display
1. A display color change

The timer/counter and external alarm inputs (hardware version 4+) can also
 trigger the audible alarm or display blinking.

The first is probably self-explanatory -- when the time matches the time that
 was set into the time slot, the alarm will sound. It's just like an alarm clock.

The second is similar to the audible alarm, but instead of beeping, it'll cause
 the display to switch to full brightness and blink at 1 Hz.

The third is a bit more unique -- it enables a new set of display colors to be
 activated when the time set into the time slot is reached. The "Set Colors
 View" described above is used to modify the colors assigned to any of these
 eight time slots as well as the date, temperature, timer/counter, main menu,
 and configuration/settings (Set Time/Date, Set Bits, and Set Value) views.

### Other modes

At this point, you should have a feel for how to select a given mode by using
 the main menu view. (If not, scroll up and (re)read the Main Menu view section
 above.) On the back of the PCB you'll find a listing of all of the
 clock's various operating modes; the numbers seen in that list correspond
 directly to what you can select in the main menu view. Let's go through them
 now.

#### Modes 1 and 2: Time/Date/Temperature view

These modes were mentioned briefly above, but left out some detail.

The only difference between these two modes is that mode 2 will automatically
 rotate the display between the time, date, and temperature. That aside, they
 behave the same, as they both use the Time/Date/Temperature view as described
 above.

In mode 2, it is possible to adjust how long the time, date, and temperature
 each appear. The duration for each is configured by adjusting the values set in
 modes 20, 21, and 22. The values are in seconds and the defaults are 24 (time),
 3 (date), and 3 (temperature).

#### Mode 3: Timer/Counter

Mode three allows the use of the clock as a timer or counter. It can count up or
 down in seconds. See the Timer/Counter View section above.

An alarm can be triggered when the timer reaches either zero (if counting down)
 or the reset value (if counting up). The timer/counter reset value is
 determined by the value set in mode 7. This value is applied when the
 timer/counter is reset and the timer is set to count down; if set to count up,
 resetting the timer sets it to zero.

#### Mode 4: DMX-512 view

This mode displays data being sent to the clock via DMX-512. If no DMX-512
 signal is present on the RS-485 serial interface, this mode does nothing and
 cannot be selected. See the DMX-512 parameters document for more information.

#### Modes 5 and 6: Set time/date view

View: Set Time/Date View

These modes were described in the "Getting Started" and "Set Time/Date View"
 sections above.

#### Mode 7: Set Timer/Counter reset value

View: Set Value View

This mode allows adjusting of the reset value for the timer/counter. Adjust the
 value up or down as desired and touch the `A` key to save it; changes are lost
 if not saved.

**Important:** You must touch the `A` key to save the new value! If you do not,
 the new value will be lost upon exiting the set value view.

#### Mode 10: Set Options Bits

View: Set Bits View

This mode is where we configure a number of options that govern the clock's
 behavior. These are options that can be either on or off (enabled or disabled).
 As such, bits represent them nicely. Each LED has a label on the back of the
 PCB that describes what it indicates is enabled or disabled in this mode, but
 we'll document them here, as well:

* LED 1: Display BCD - if set, BCD is used in all displays, otherwise binary is
 used. This setting affects all displays in all modes and menus.
* LED 2: 12-hour mode - if set, the time is displayed as a 12-hour clock
 (AM/PM), otherwise it will display as a 24-hour clock.
* LED 3: Status LED as PM indicator - if set, the status LED will light in the
 current `1` color if it is PM or the `0` color if it is AM.
* LED 4: Hourly Chime - if set, at the top of every hour, the clock will
 indicate the current hour in binary audibly using a series of high (1) and low
 (0) beeps.
* LED 5: DST Enabled - if set, the clock will adjust itself automatically for
 daylight savings time (DST) based on values configured in settings 24 through
 29 (see below).
* LED 6: Display Fahrenheit - temperature is shown in degrees Fahrenheit if set,
 Celsius otherwise.
* LED 7: Fade Across Slots - if set, display colors will gradually change as
 time progresses from one configured time slot to the next. If disabled, colors
 will abruptly change when a time slot configured for color change is reached.
* LED 8: Automatic Intensity Adjustment - if set, the display brightness will
 automatically adjust based on the ambient light level. If clear, manual
 adjustment is enabled when the time, date, or temperature is displayed.
* LED 9: DMX-512 Extended mode - if set, additional DMX-512 channels are used
 enabling enhanced control of the clock via the control protocol.
* LED 10: Startup To Toggle - if set, the clock defaults to mode 2 when powered
 on or when left idle for more than one minute. Otherwise, mode 1 is the default.
* LED 11: MSbs Off - when set, LEDs that would otherwise be leading zeros are
 turned off in the time, date, temperature, and timer/counter views.

#### Modes 11 through 13: Time slot/Alarm behavior bits

View: Set Bits View

Each of these three modes allows enabling or disabling of each of the three
 behaviors described in the "Time Slots" section above. LEDs 1 through 8
 correspond to time slots 1 through 8, LED 9 corresponds to the timer/counter,
 and (on hardware version 4+) LEDs 10 and 11 correspond to the external alarm
 input pins (latching and momentary, respectively).

Mode 11 allows enabling or disabling the audible alarms/beeping, mode 12 allows
 enabling or disabling the display blinking, and mode 13 allows enabling or
 disabling color changes.

By default, color changes are enabled for all eight time slots while the audible
 alarms and display blinking are disabled for all eight time slots.

#### Modes 20 through 22: Time, Date, and Temperature display durations

View: Set Value View

As was described above, these three modes allow the adjustment of how long (in
 seconds) the time, date, and temperature will appear when the clock is
 operating in mode 2.

#### Mode 23: Fade duration

View: Set Value View

This mode allows the adjustment of the duration of the fading that occurs as
 bits on the display toggle from `0` to `1` or vice-versa. This effect is used
 in display modes 1, 2, and 3. The value set describes the fade duration in
 milliseconds and the default is 100.

#### Modes 24 through 29: Daylight Savings Time (DST) settings

View: Set Value View

These modes allow the configuration of exactly when clock adjustments occur due
 to DST beginning and ending. The default values correspond with DST changes
 that occur in the US.

Mode 24 allows setting the month in which DST begins.\
Mode 25 allows setting the day of week ordinal (first, second, third, fourth) in
 which DST begins.\
Mode 26 allows setting the month in which DST ends.\
Mode 27 allows setting the day of week ordinal (first, second, third, fourth) in
 which DST ends.\
Mode 28 allows setting the day of the week on which the DST time change occurs.\
Mode 29 allows setting the hour at which the DST time change occurs.

#### Mode 30: Minimum Intensity

View: Set Value View

This mode allows the adjustment of the minimum intensity allowed when automatic
 intensity adjustments are enabled (see mode 10). It is intended to keep the
 display from dimming _too much_.

#### Mode 31: Flicker Reduction

View: Set Value View

This is a technique used on pre-version 4 clocks that use the TLC5947 LED
 drivers. When the display intensity drops below the value determined by this
 setting, the hardware will strobe the drivers' BLANK pin as data is latched
 into the drivers, helping to mitigate flickering or pulsing of the display when
 frequent display refreshes are occurring. Combined with the setting defined in
 mode 36, this effect can be nearly eliminated. Note that this setting is not
 used by version 4+ clocks as it is not necessary with the TLC5951 LED drivers.

#### Mode 32: Current Drive

View: Set Value View

This mode allows software-based adjustment of the level of current the TLC59xx
 drivers allow through the display LEDs. In doing so, it effectively makes the
 LEDs dimmer or brighter. Lower current levels may lengthen the life of the LEDs
 and will also keep the drivers cooler.

#### Mode 33: Temperature Calibration

View: Set Value View

When using the STM32's internal temperature sensor, some calibration value is
 required as they're not all consistent. This mode allows the adjustment of this
 calibration value. Note that it is a **negative** value, so increasing the
 value will _decrease_ the temperature readout.

#### Mode 34: Beeper Volume

View: Set Value View

This mode allows adjusting of the beeper volume. Higher numbers mean a louder
 beeper. This setting affects all sounds the beeper produces. Easy enough, yeah?

#### Mode 35: Date Format

View: Set Value View

This mode allows adjusting of the way the year, month, and day are arranged on
 the display when the date appears. The possible values are zero (the default),
 one, or two, and they correspond to the following arrangements:
* 0: Year, Month, Day
* 1: Day, Month, Year
* 2: Month, Day, Year

Note that this setting affects how the date is displayed both when viewing the
 date (mode 1 or 2) **and** when setting the date (in mode 6).

#### Mode 36: Display Hardware Refresh Interval

View: Set Value View

This mode allows adjustment of the display hardware refresh interval. It
 determines the maximum frequency at which data may be latched into the TLC59xx
 drivers. On pre-version 4 hardware that uses the TLC5947 drivers, this setting,
 in conjunction with the setting defined in mode 31, helps reduce flicker or
 pulsing during frequent display refreshes. This setting should be left at the
 default value of zero on version 4+ clocks as the TLC5951 drivers have a
 better, built-in mechanism that eliminates flicker and pulsing. For pre-v4
 clocks, the recommended value for this setting is ten (10).

#### Mode 39: DMX-512 Address

View: Set Value View

This mode allows setting of the clock's DMX-512 address. If DMX-512 is not in
 use, this setting is irrelevant. See the DMX-512 parameters document for more
 information.

#### Modes 40 through 47: Set Slot Times

View: Set Time/Date View

These modes allow setting of the time for each of the eight time slots. See the
"Time Slots" section above for more information.

#### Modes 50 through 62: Set (Slot) Colors

View: Set Colors View

These modes allow setting of the color pairs associated with each of the eight
 time slots, the date, the temperature, the timer/counter, the main menu view,
 and the configuration/settings (Set Time/Date, Set Bits, and Set Value) views.
 See the "Time Slots" section above for more information.

 **Footnote:** Yes, I said **year**, **month**, **day**, the way the date is
  _supposed_ to be written/displayed. ;) If you don't like it, there is a setting
  that can be modified to change it. You're welcome. :p

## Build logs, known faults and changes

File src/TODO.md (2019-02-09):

# kbx's RGB Binary Clock

## TODO List and Issue Tracking

### Known issues

1. In pre-v3 hardware, DMA channels are shared between USART1 and USART2; as
 such, calls to readSerial() and writeSerial() functions may squash the other's
 DMA. This works with the code as-is at the time of this writing, but will
 likely present problems and create confusion for others using these parts of
 the code. This should be handled better.

## General TODO

1. Better/"learning" automatic brightness control

## v4 TODO

1. Better match status LED colors with main display colors
1. (Maybe) Color correction tweaks using the TLC5951's DC

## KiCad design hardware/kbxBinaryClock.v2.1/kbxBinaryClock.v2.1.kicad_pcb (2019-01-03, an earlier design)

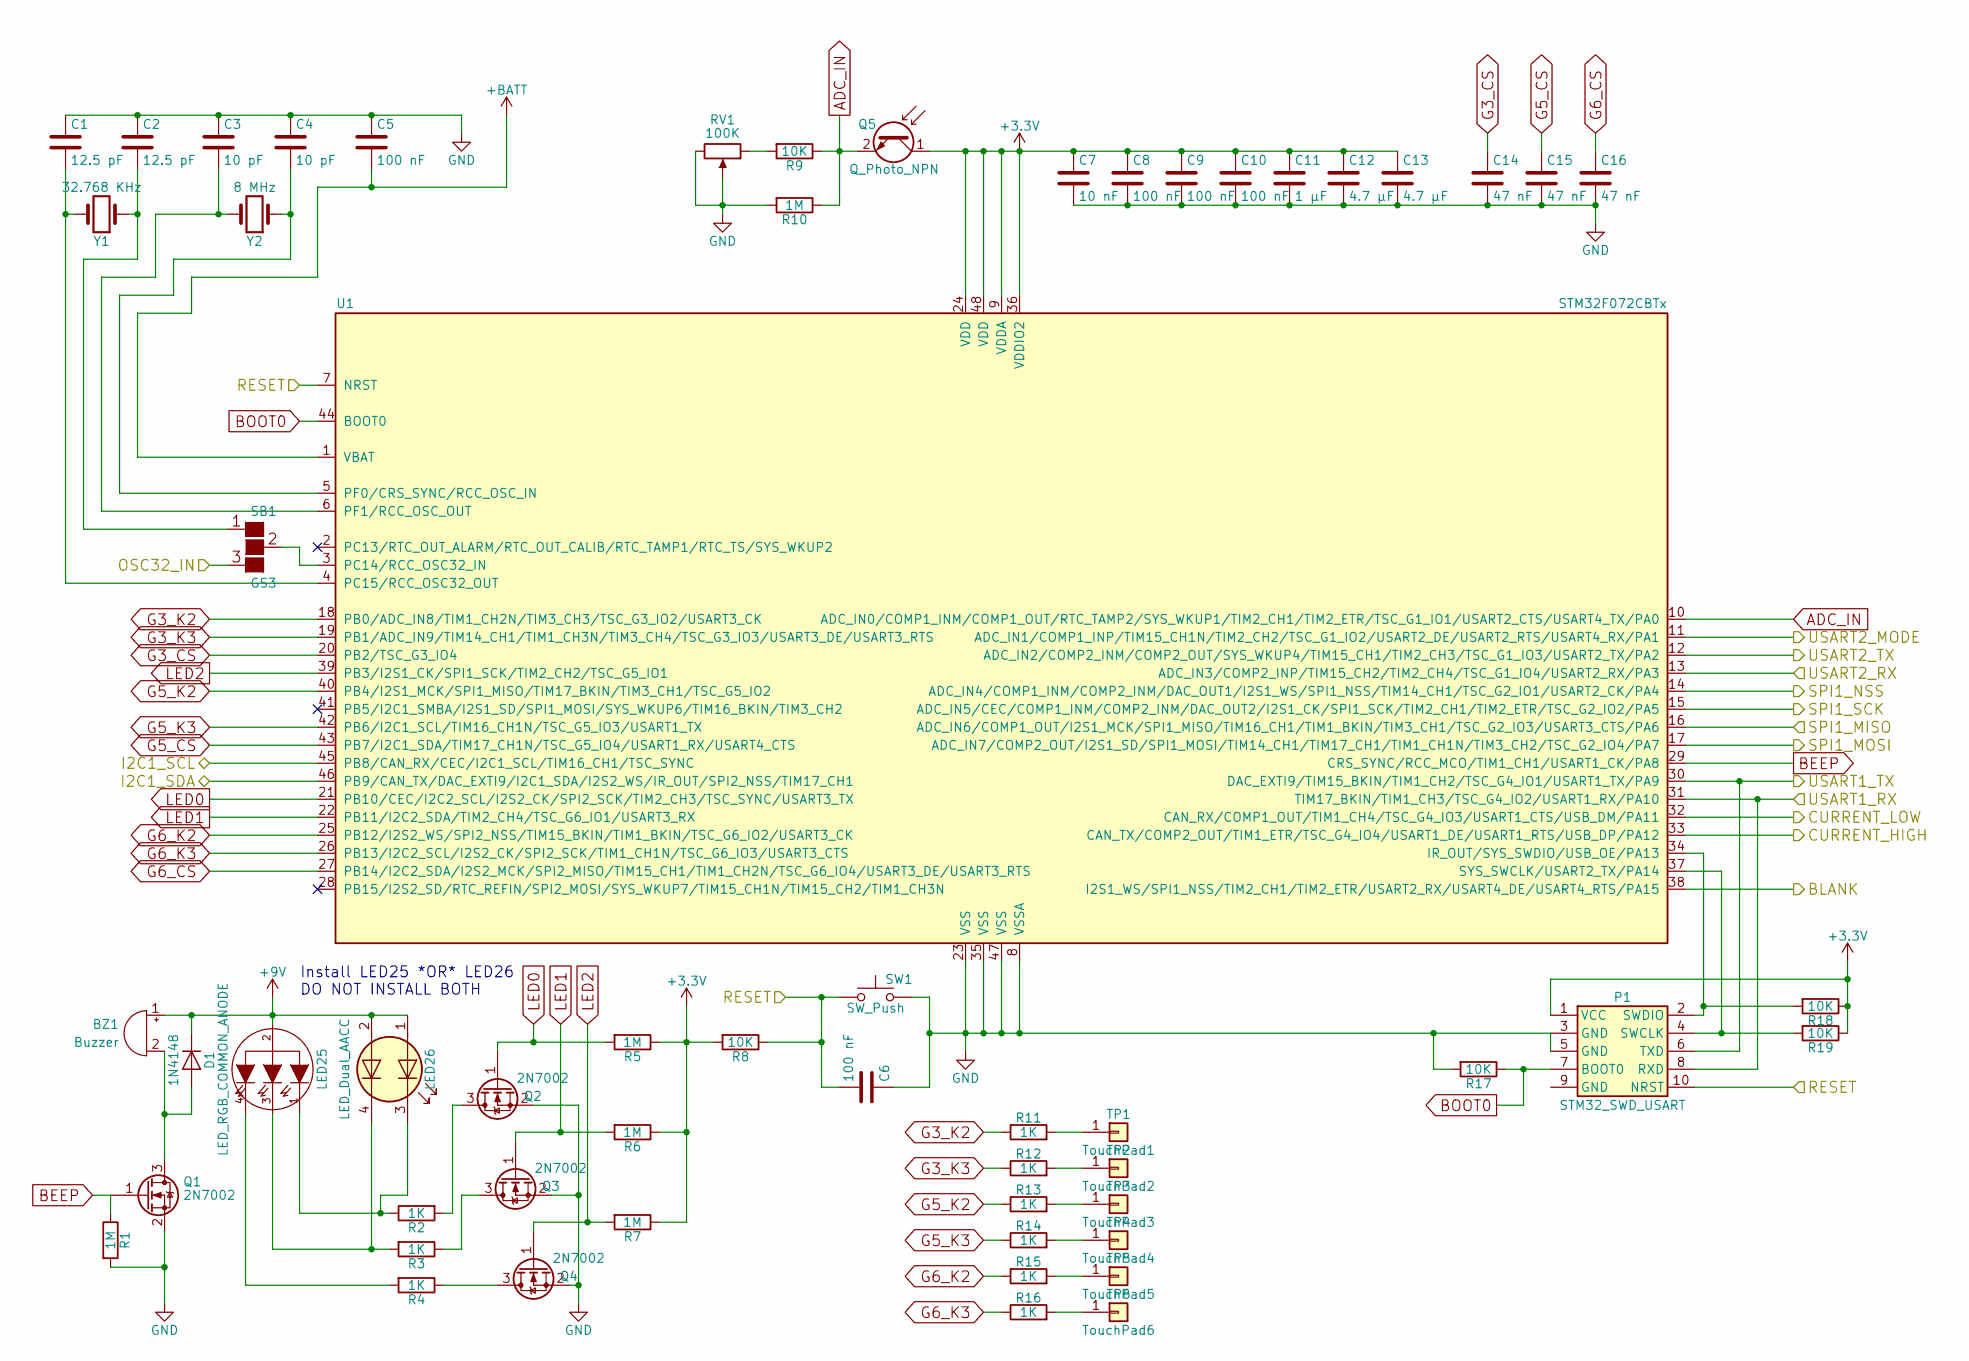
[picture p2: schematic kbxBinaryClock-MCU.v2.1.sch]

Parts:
BZ1: Buzzer; Buzzer_12x9.5RM7.6
C1, C2: 12.5 pF; C_0805
C3, C4: 10 pF; C_0805
C5, C6, C8, C9, C10: 100 nF; C_0805
C7: 10 nF; C_0805
C11: 1 µF; C_0805
C12, C13: 4.7 µF; C_0805
C14, C15, C16: 47 nF; C_0805
D1: 1N4148; D_SOD-123
LED25: LED_RGB_COMMON_ANODE; LED_D5.0mm-4
LED26: LED_Dual_AACC; LED_Cree-PLCC4_3.2x2.8mm_CCW
P1: STM32_SWD_USART; Pin_Header_Straight_2x05_Pitch1.27mm_SMD
Q1, Q2, Q3, Q4: 2N7002; SOT-23
Q5: Q_Photo_NPN; LED_D5.0mm
R1, R5, R6, R7, R10: 1M; R_0805
R2, R3, R4, R11, R12, R13, R14, R15, R16: 1K; R_0805
R8, R9, R17, R18, R19: 10K; R_0805
RV1: 100K; Potentiometer_Trimmer_Vishay_TS53YJ
SB1: GS3
SW1: SW_Push; SW_SPST_KMR2
TP1: TouchPad1
TP2: TouchPad2; TouchPad1
TP3: TouchPad3; TouchPad1
TP4: TouchPad4; TouchPad1
TP5: TouchPad5; TouchPad1
TP6: TouchPad6; TouchPad1
U1: STM32F072CBTx; LQFP-48_7x7mm_Pitch0.5mm
Y1: 32.768 KHz; Crystal_SMD_3215-2pin_3.2x1.5mm
Y2: 8 MHz; Crystal_SMD_5032-4pin_5.0x3.2mm

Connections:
+3V3: C7.1, C8.1, C9.1, C10.1, C11.1, C12.1, C13.1, P1.1 (VCC), Q5.1 (C), R5.1, R6.1, R7.1, R8.2, R18.1, R19.1, U1.9 (VDDA), U1.24 (VDD), U1.36 (VDDIO2), U1.48 (VDD); also elsewhere on the board
+9V: BZ1.1 (-), D1.1 (K), LED25.2 (COMMON), LED26.1 (A1), LED26.2 (A2); also elsewhere on the board
+BATT: C5.2, U1.1 (VBAT); also elsewhere on the board
/Display/BLANK: U1.38 (I2S1_WS/SPI1_NSS/TIM2_CH1/TIM2_ETR/USAR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); also elsewhere on the board
/Display/CURRENT_HIGH: U1.33 (CAN_TX/COMP2_OUT/TIM1_ETR/TSC_G4_IO4/US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); also elsewhere on the board
/Display/CURRENT_LOW: U1.32 (CAN_RX/COMP1_OUT/TIM1_CH4/TSC_G4_IO3/US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); also elsewhere on the board
/Display/SPI1_MISO: U1.16 (ADC_IN6/COMP1_OUT/I2S1_MCK/SPI1_MISO/TI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); also elsewhere on the board
/Display/SPI1_MOSI: U1.17 (ADC_IN7/COMP2_OUT/I2S1_SD/SPI1_MOSI/TIM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); also elsewhere on the board
/Display/SPI1_NSS: U1.14 (ADC_IN4/COMP1_INM/COMP2_INM/DAC_OUT1/I2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); also elsewhere on the board
/Display/SPI1_SCK: U1.15 (ADC_IN5/CEC/COMP1_INM/COMP2_INM/DAC_OUT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); also elsewhere on the board
/MCU/I2C1_SCL: U1.45 (PB8/CAN_RX/CEC/I2C1_SCL/TIM16_CH1/TSC_S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); also elsewhere on the board
/MCU/I2C1_SDA: U1.46 (PB9/CAN_TX/DAC_EXTI9/I2C1_SDA/I2S2_WS/I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); also elsewhere on the board
/MCU/OSC32_IN: SB1.3 (G3); also elsewhere on the board
/MCU/RESET: C6.2, P1.10 (NRST), R8.1, SW1.1, U1.7 (NRST); also elsewhere on the board
/MCU/USART1_RX: P1.8 (RXD), U1.31 (TIM17_BKIN/TIM1_CH3/TSC_G4_IO2/USART1_R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); also elsewhere on the board
/MCU/USART1_TX: P1.6 (TXD), U1.30 (DAC_EXTI9/TIM15_BKIN/TIM1_CH2/TSC_G4_IO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); also elsewhere on the board
/MCU/USART2_MODE: U1.11 (ADC_IN1/COMP1_INP/TIM15_CH1N/TIM2_CH2/T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); also elsewhere on the board
/MCU/USART2_RX: U1.13 (ADC_IN3/COMP2_INP/TIM15_CH2/TIM2_CH4/TS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); also elsewhere on the board
/MCU/USART2_TX: U1.12 (ADC_IN2/COMP2_INM/COMP2_OUT/SYS_WKUP4/T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); also elsewhere on the board
ADC_IN: Q5.2 (E), R9.1, R10.1, U1.10 (ADC_IN0/COMP1_INM/COMP1_OUT/RTC_TAMP2/S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)
BEEP: Q1.1 (G), R1.1, U1.29 (CRS_SYNC/RCC_MCO/TIM1_CH1/USART1_CK/PA8)
BOOT0: P1.7 (BOOT0), R17.1, U1.44 (BOOT0)
G3_CS: C14.1, U1.20 (PB2/TSC_G3_IO4)
G3_K2: R11.1, U1.18 (PB0/ADC_IN8/TIM1_CH2N/TIM3_CH3/TSC_G3_I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)
G3_K3: R12.1, U1.19 (PB1/ADC_IN9/TIM14_CH1/TIM1_CH3N/TIM3_CH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)
G5_CS: C15.1, U1.43 (PB7/I2C1_SDA/TIM17_CH1N/TSC_G5_IO4/USAR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)
G5_K2: R13.1, U1.40 (PB4/I2S1_MCK/SPI1_MISO/TIM17_BKIN/TIM3_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)
G5_K3: R14.1, U1.42 (PB6/I2C1_SCL/TIM16_CH1N/TSC_G5_IO3/USAR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)
G6_CS: C16.1, U1.27 (PB14/I2C2_SDA/I2S2_MCK/SPI2_MISO/TIM15_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)
G6_K2: R15.1, U1.25 (PB12/I2S2_WS/SPI2_NSS/TIM15_BKIN/TIM1_B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)
G6_K3: R16.1, U1.26 (PB13/I2C2_SCL/I2S2_CK/SPI2_SCK/TIM1_CH1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)
GND: C1.1, C2.1, C3.1, C4.1, C5.1, C6.1, C7.2, C8.2, C9.2, C10.2, C11.2, C12.2, C13.2, C14.2, C15.2, C16.2, P1.3 (GND), P1.5 (GND), Q1.2 (S), Q2.2 (S), Q3.2 (S), Q4.2 (S), R1.2, R10.2, R17.2, RV1.2, RV1.3, SW1.2, U1.8 (VSSA), U1.23 (VSS), U1.35 (VSS), U1.47 (VSS); also elsewhere on the board
LED0: Q2.1 (G), R5.2, U1.21 (PB10/CEC/I2C2_SCL/I2S2_CK/SPI2_SCK/TIM2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)
LED1: Q3.1 (G), R6.2, U1.22 (PB11/I2C2_SDA/TIM2_CH4/TSC_G6_IO1/USART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)
LED2: Q4.1 (G), R7.2, U1.39 (PB3/I2S1_CK/SPI1_SCK/TIM2_CH2/TSC_G5_IO1)
unnamed: BZ1.2 (+), D1.2 (A), Q1.3 (D)
unnamed: C1.2, U1.4 (PC15/RCC_OSC32_OUT), Y1.2
unnamed: C2.2, SB1.1 (G1), Y1.1
unnamed: C3.2, U1.6 (PF1/RCC_OSC_OUT), Y2.2
unnamed: C4.2, U1.5 (PF0/CRS_SYNC/RCC_OSC_IN), Y2.1
unnamed: LED25.1 (RED), LED26.3 (K1), R2.1
unnamed: LED25.3 (GREEN), LED26.4 (K2), R3.2
unnamed: LED25.4 (BLUE), R4.2
unnamed: P1.2 (SWDIO), R18.2, U1.34 (IR_OUT/SYS_SWDIO/USB_OE/PA13)
unnamed: P1.4 (SWCLK), R19.2, U1.37 (SYS_SWCLK/USART2_TX/PA14)
unnamed: Q2.3 (D), R2.2
unnamed: Q3.3 (D), R3.1
unnamed: Q4.3 (D), R4.1
unnamed: R9.2, RV1.1
unnamed: R11.2, TP1.1
unnamed: R12.2, TP2.1
unnamed: R13.2, TP3.1
unnamed: R14.2, TP4.1
unnamed: R15.2, TP5.1
unnamed: R16.2, TP6.1
unnamed: SB1.2 (G2), U1.3 (PC14/RCC_OSC32_IN)

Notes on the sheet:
Install LED25 *OR* LED26 DO NOT INSTALL BOTH

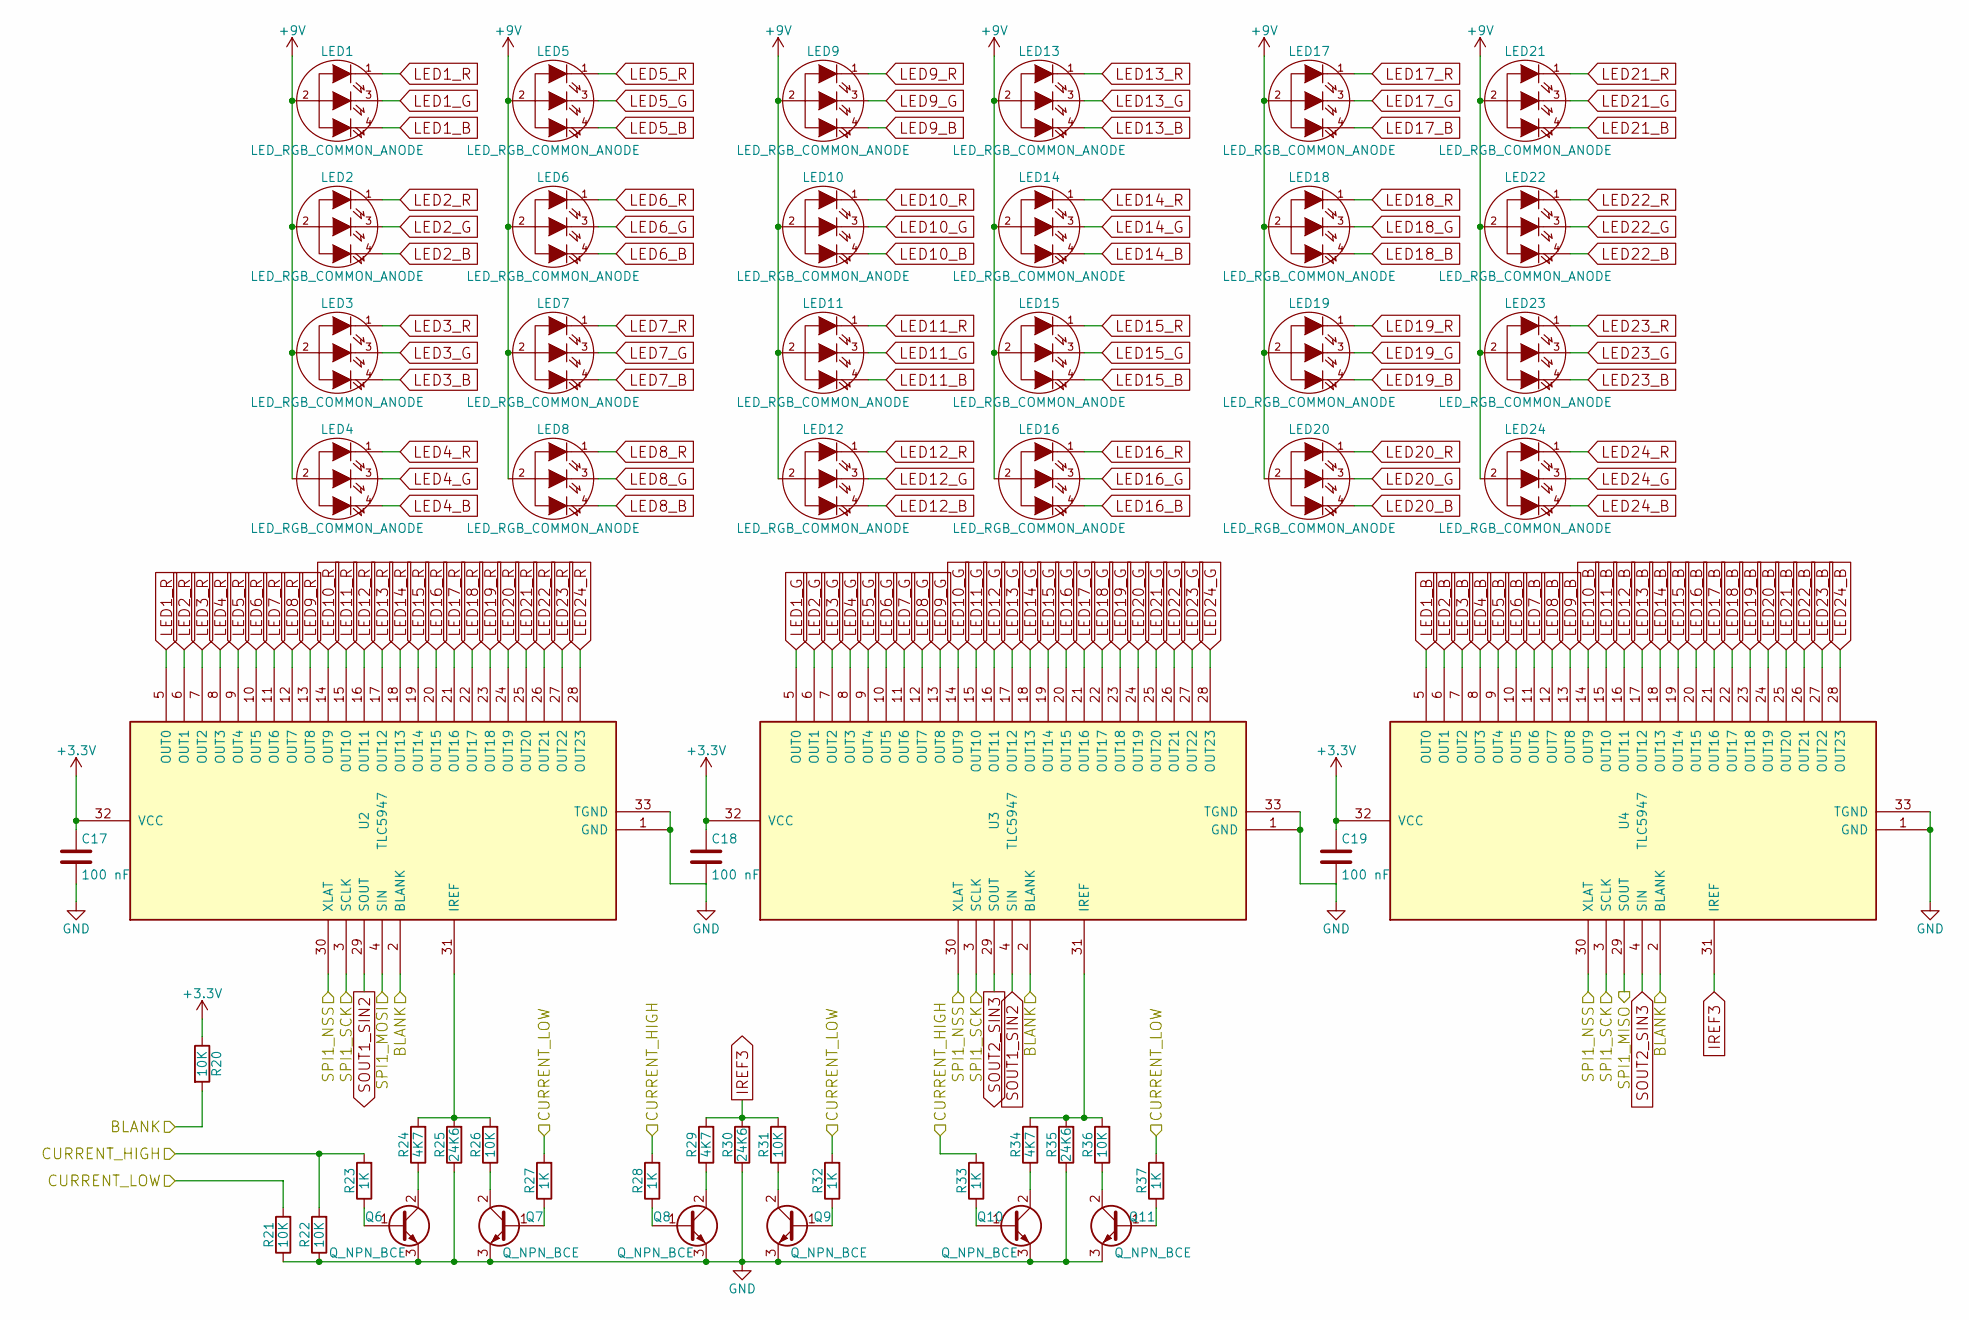
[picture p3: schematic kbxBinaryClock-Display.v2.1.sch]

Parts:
C17, C18, C19: 100 nF; C_0805
LED1, LED2, LED3, LED4, LED5, LED6, LED7, LED8, LED9, LED10, LED11, LED12, LED13, LED14, LED15, LED16, LED17, LED18, LED19, LED20, LED21, LED22, LED23, LED24: LED_RGB_COMMON_ANODE; LED_D5.0mm-4
Q6, Q7, Q8, Q9, Q10, Q11: Q_NPN_BCE; SOT-23
R20, R21, R22, R26, R31, R36: 10K; R_0805
R23, R27, R28, R32, R33, R37: 1K; R_0805
R24, R29, R34: 4K7; R_0805
R25, R30, R35: 24K6; R_0805
U2, U3, U4: TLC5947; HTSSOP-32_6.1x11mm_Pitch0.65mm_ThermalPad

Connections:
+3V3: C17.1, C18.1, C19.1, R20.1, U2.32 (VCC), U3.32 (VCC), U4.32 (VCC); also elsewhere on the board
+9V: LED1.2 (COMMON), LED2.2 (COMMON), LED3.2 (COMMON), LED4.2 (COMMON), LED5.2 (COMMON), LED6.2 (COMMON), LED7.2 (COMMON), LED8.2 (COMMON), LED9.2 (COMMON), LED10.2 (COMMON), LED11.2 (COMMON), LED12.2 (COMMON), LED13.2 (COMMON), LED14.2 (COMMON), LED15.2 (COMMON), LED16.2 (COMMON), LED17.2 (COMMON), LED18.2 (COMMON), LED19.2 (COMMON), LED20.2 (COMMON), LED21.2 (COMMON), LED22.2 (COMMON), LED23.2 (COMMON), LED24.2 (COMMON); also elsewhere on the board
/Display/BLANK: R20.2, U2.2 (BLANK), U3.2 (BLANK), U4.2 (BLANK); also elsewhere on the board
/Display/CURRENT_HIGH: R22.2, R23.2, R28.2, R33.2; also elsewhere on the board
/Display/CURRENT_LOW: R21.2, R27.2, R32.2, R37.2; also elsewhere on the board
/Display/SPI1_MISO: U4.29 (SOUT); also elsewhere on the board
/Display/SPI1_MOSI: U2.4 (SIN); also elsewhere on the board
/Display/SPI1_NSS: U2.30 (XLAT), U3.30 (XLAT), U4.30 (XLAT); also elsewhere on the board
/Display/SPI1_SCK: U2.3 (SCLK), U3.3 (SCLK), U4.3 (SCLK); also elsewhere on the board
GND: C17.2, C18.2, C19.2, Q6.3 (E), Q7.3 (E), Q8.3 (E), Q9.3 (E), Q10.3 (E), Q11.3 (E), R21.1, R22.1, R25.1, R30.1, R35.1, U2.1 (GND), U2.33 (TGND), U3.1 (GND), U3.33 (TGND), U4.1 (GND), U4.33 (TGND); also elsewhere on the board
IREF3: R29.2, R30.2, R31.2, U4.31 (IREF)
LED1_B: LED1.4 (BLUE), U4.5 (OUT0)
LED1_G: LED1.3 (GREEN), U3.5 (OUT0)
LED1_R: LED1.1 (RED), U2.5 (OUT0)
LED2_B: LED2.4 (BLUE), U4.6 (OUT1)
LED2_G: LED2.3 (GREEN), U3.6 (OUT1)
LED2_R: LED2.1 (RED), U2.6 (OUT1)
LED3_B: LED3.4 (BLUE), U4.7 (OUT2)
LED3_G: LED3.3 (GREEN), U3.7 (OUT2)
LED3_R: LED3.1 (RED), U2.7 (OUT2)
LED4_B: LED4.4 (BLUE), U4.8 (OUT3)
LED4_G: LED4.3 (GREEN), U3.8 (OUT3)
LED4_R: LED4.1 (RED), U2.8 (OUT3)
LED5_B: LED5.4 (BLUE), U4.9 (OUT4)
LED5_G: LED5.3 (GREEN), U3.9 (OUT4)
LED5_R: LED5.1 (RED), U2.9 (OUT4)
LED6_B: LED6.4 (BLUE), U4.10 (OUT5)
LED6_G: LED6.3 (GREEN), U3.10 (OUT5)
LED6_R: LED6.1 (RED), U2.10 (OUT5)
LED7_B: LED7.4 (BLUE), U4.11 (OUT6)
LED7_G: LED7.3 (GREEN), U3.11 (OUT6)
LED7_R: LED7.1 (RED), U2.11 (OUT6)
LED8_B: LED8.4 (BLUE), U4.12 (OUT7)
LED8_G: LED8.3 (GREEN), U3.12 (OUT7)
LED8_R: LED8.1 (RED), U2.12 (OUT7)
LED9_B: LED9.4 (BLUE), U4.13 (OUT8)
LED9_G: LED9.3 (GREEN), U3.13 (OUT8)
LED9_R: LED9.1 (RED), U2.13 (OUT8)
LED10_B: LED10.4 (BLUE), U4.14 (OUT9)
LED10_G: LED10.3 (GREEN), U3.14 (OUT9)
LED10_R: LED10.1 (RED), U2.14 (OUT9)
LED11_B: LED11.4 (BLUE), U4.15 (OUT10)
LED11_G: LED11.3 (GREEN), U3.15 (OUT10)
LED11_R: LED11.1 (RED), U2.15 (OUT10)
LED12_B: LED12.4 (BLUE), U4.16 (OUT11)
LED12_G: LED12.3 (GREEN), U3.16 (OUT11)
LED12_R: LED12.1 (RED), U2.16 (OUT11)
LED13_B: LED13.4 (BLUE), U4.17 (OUT12)
LED13_G: LED13.3 (GREEN), U3.17 (OUT12)
LED13_R: LED13.1 (RED), U2.17 (OUT12)
LED14_B: LED14.4 (BLUE), U4.18 (OUT13)
LED14_G: LED14.3 (GREEN), U3.18 (OUT13)
LED14_R: LED14.1 (RED), U2.18 (OUT13)
LED15_B: LED15.4 (BLUE), U4.19 (OUT14)
LED15_G: LED15.3 (GREEN), U3.19 (OUT14)
LED15_R: LED15.1 (RED), U2.19 (OUT14)
LED16_B: LED16.4 (BLUE), U4.20 (OUT15)
LED16_G: LED16.3 (GREEN), U3.20 (OUT15)
LED16_R: LED16.1 (RED), U2.20 (OUT15)
LED17_B: LED17.4 (BLUE), U4.21 (OUT16)
LED17_G: LED17.3 (GREEN), U3.21 (OUT16)
LED17_R: LED17.1 (RED), U2.21 (OUT16)
LED18_B: LED18.4 (BLUE), U4.22 (OUT17)
LED18_G: LED18.3 (GREEN), U3.22 (OUT17)
LED18_R: LED18.1 (RED), U2.22 (OUT17)
LED19_B: LED19.4 (BLUE), U4.23 (OUT18)
LED19_G: LED19.3 (GREEN), U3.23 (OUT18)
LED19_R: LED19.1 (RED), U2.23 (OUT18)
LED20_B: LED20.4 (BLUE), U4.24 (OUT19)
LED20_G: LED20.3 (GREEN), U3.24 (OUT19)
LED20_R: LED20.1 (RED), U2.24 (OUT19)
LED21_B: LED21.4 (BLUE), U4.25 (OUT20)
LED21_G: LED21.3 (GREEN), U3.25 (OUT20)
LED21_R: LED21.1 (RED), U2.25 (OUT20)
LED22_B: LED22.4 (BLUE), U4.26 (OUT21)
LED22_G: LED22.3 (GREEN), U3.26 (OUT21)
LED22_R: LED22.1 (RED), U2.26 (OUT21)
LED23_B: LED23.4 (BLUE), U4.27 (OUT22)
LED23_G: LED23.3 (GREEN), U3.27 (OUT22)
LED23_R: LED23.1 (RED), U2.27 (OUT22)
LED24_B: LED24.4 (BLUE), U4.28 (OUT23)
LED24_G: LED24.3 (GREEN), U3.28 (OUT23)
LED24_R: LED24.1 (RED), U2.28 (OUT23)
unnamed: Q6.1 (B), R23.1
unnamed: Q6.2 (C), R24.1
unnamed: Q7.1 (B), R27.1
unnamed: Q7.2 (C), R26.1
unnamed: Q8.1 (B), R28.1
unnamed: Q8.2 (C), R29.1
unnamed: Q9.1 (B), R32.1
unnamed: Q9.2 (C), R31.1
unnamed: Q10.1 (B), R33.1
unnamed: Q10.2 (C), R34.1
unnamed: Q11.1 (B), R37.1
unnamed: Q11.2 (C), R36.1
unnamed: R24.2, R25.2, R26.2, U2.31 (IREF)
unnamed: R34.2, R35.2, R36.2, U3.31 (IREF)
SOUT1_SIN2: U2.29 (SOUT), U3.4 (SIN)
SOUT2_SIN3: U3.29 (SOUT), U4.4 (SIN)

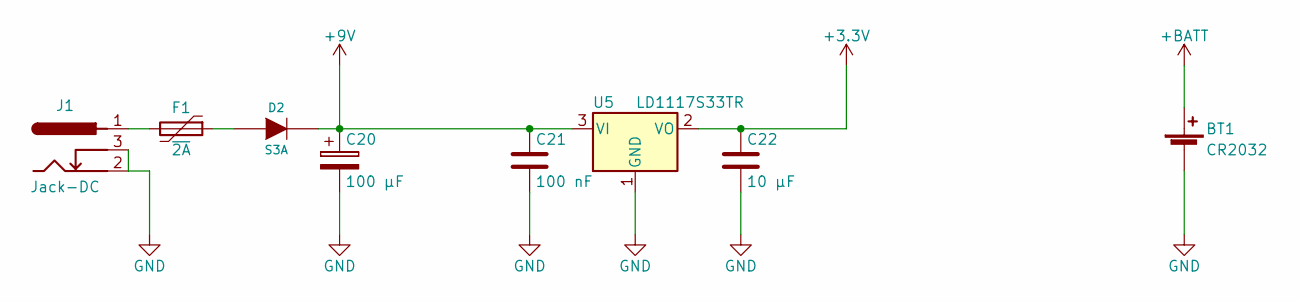
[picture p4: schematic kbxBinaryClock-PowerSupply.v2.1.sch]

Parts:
BT1: CR2032; Keystone_103_1x20mm-CoinCell
C20: 100 µF; CP_Elec_8x10
C21: 100 nF; C_0805
C22: 10 µF; C_0805
D2: S3A; D_SMC
F1: ~2A; Fuse_SMD2920
J1: Jack-DC; BARREL_JACK
U5: LD1117S33TR; TO-252-2

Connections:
+3V3: C22.1, U5.2 (VO); also elsewhere on the board
+9V: C20.1, C21.1, D2.2 (K), U5.3 (VI); also elsewhere on the board
+BATT: BT1.1 (+); also elsewhere on the board
GND: BT1.2 (-), C20.2, C21.2, C22.2, J1.2, J1.3, U5.1 (GND); also elsewhere on the board
unnamed: D2.1 (A), F1.1
unnamed: F1.2, J1.1

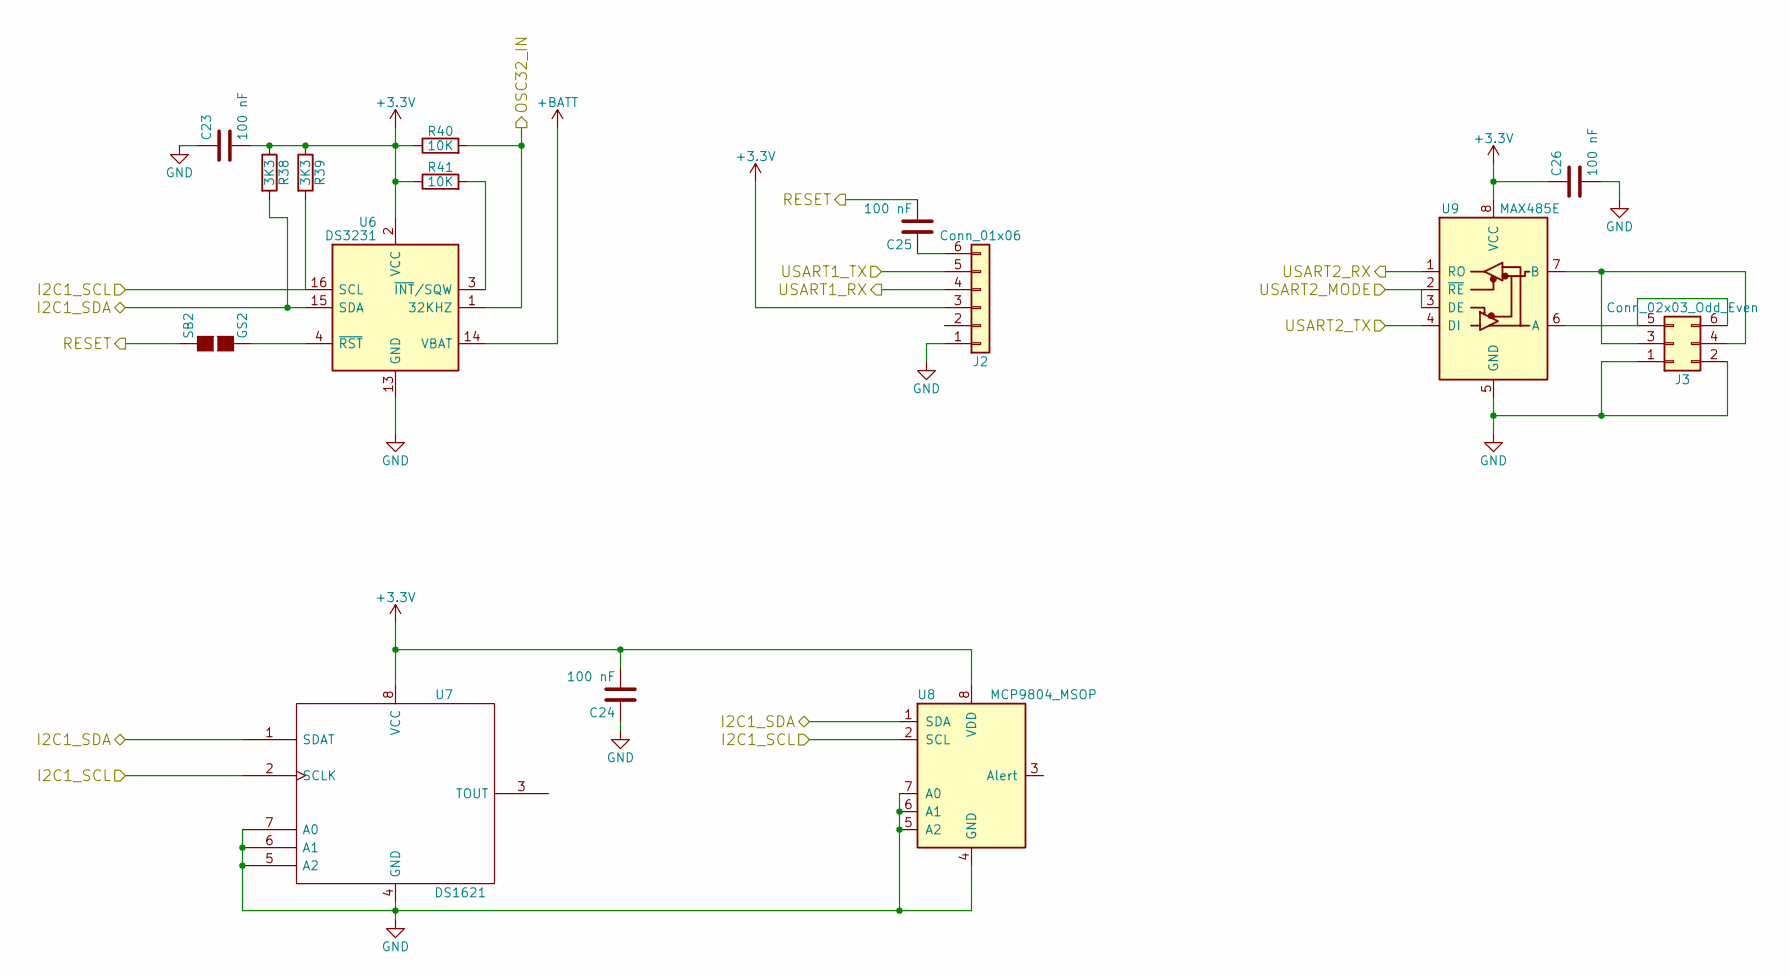
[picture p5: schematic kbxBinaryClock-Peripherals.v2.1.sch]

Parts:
C23, C24, C25, C26: 100 nF; C_0805
J2: Conn_01x06; Pin_Header_Straight_1x06_Pitch2.54mm
J3: Conn_02x03_Odd_Even; Pin_Header_Straight_2x03_Pitch2.54mm
R38, R39: 3K3; R_0805
R40, R41: 10K; R_0805
SB2: GS2
U6: DS3231; SOIC-16W_7.5x10.3mm_Pitch1.27mm
U7: DS1621; SOIC-8_3.9x4.9mm_Pitch1.27mm
U8: MCP9804_MSOP; MSOP-8_3x3mm_Pitch0.65mm
U9: MAX485E; SOIC-8_3.9x4.9mm_Pitch1.27mm

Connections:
+3V3: C23.2, C24.2, C26.1, J2.3, R38.1, R39.1, R40.1, R41.1, U6.2 (VCC), U7.8 (VCC), U8.8 (VDD), U9.8 (VCC); also elsewhere on the board
+BATT: U6.14 (VBAT); also elsewhere on the board
/MCU/I2C1_SCL: R39.2, U6.16 (SCL), U7.2 (SCLK), U8.2 (SCL); also elsewhere on the board
/MCU/I2C1_SDA: R38.2, U6.15 (SDA), U7.1 (SDAT), U8.1 (SDA); also elsewhere on the board
/MCU/OSC32_IN: R40.2, U6.1 (32KHZ); also elsewhere on the board
/MCU/RESET: C25.2, SB2.1 (G1); also elsewhere on the board
/MCU/USART1_RX: J2.4; also elsewhere on the board
/MCU/USART1_TX: J2.5; also elsewhere on the board
/MCU/USART2_MODE: U9.2 (~RE), U9.3 (DE); also elsewhere on the board
/MCU/USART2_RX: U9.1 (RO); also elsewhere on the board
/MCU/USART2_TX: U9.4 (DI); also elsewhere on the board
GND: C23.1, C24.1, C26.2, J2.1, J3.1, J3.2, U6.5 (NC), U6.6 (NC), U6.7 (NC), U6.8 (NC), U6.9 (NC), U6.10 (NC), U6.11 (NC), U6.12 (NC), U6.13 (GND), U7.4 (GND), U7.5 (A2), U7.6 (A1), U7.7 (A0), U8.4 (GND), U8.5 (A2), U8.6 (A1), U8.7 (A0), U9.5 (GND); also elsewhere on the board
unnamed: C25.1, J2.6
unnamed: J3.3, J3.4, U9.7 (B)
unnamed: J3.5, J3.6, U9.6 (A)
unnamed: R41.2, U6.3 (~INT~/SQW)
unnamed: SB2.2 (G2), U6.4 (~RST)

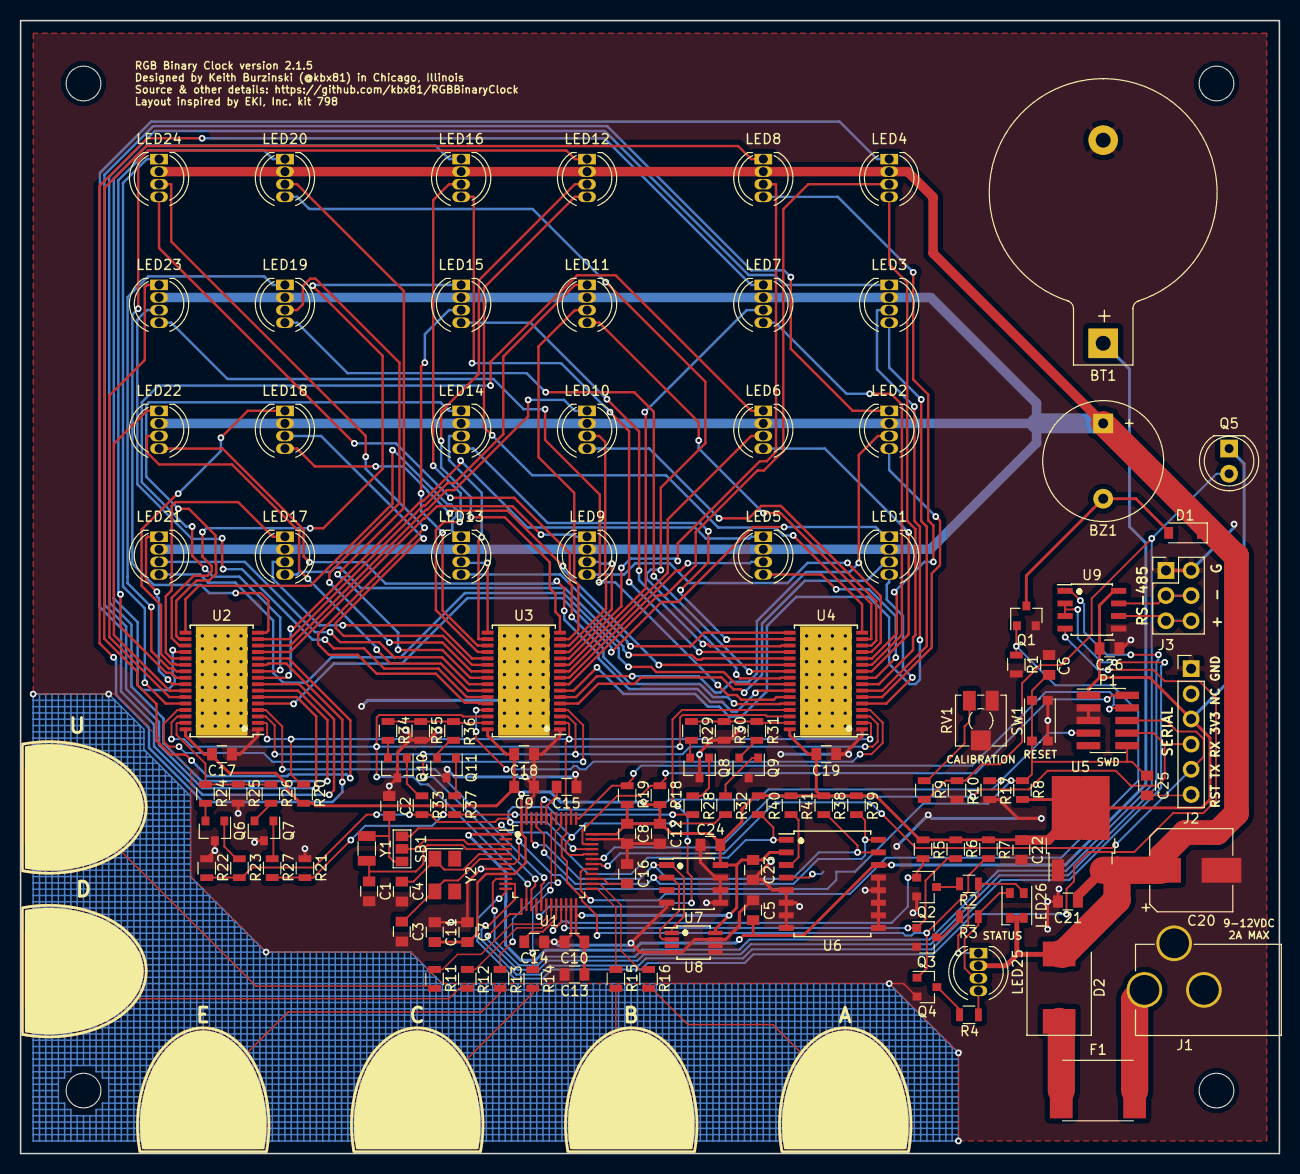
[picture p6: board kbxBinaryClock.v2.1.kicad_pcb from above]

Board: 2 copper layers, 127.0 x 114.3 mm, 138 parts (1 on the bottom side), 152 nets.

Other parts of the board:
MH1, MH2, MH3, MH4: MountingHole_3.5mm

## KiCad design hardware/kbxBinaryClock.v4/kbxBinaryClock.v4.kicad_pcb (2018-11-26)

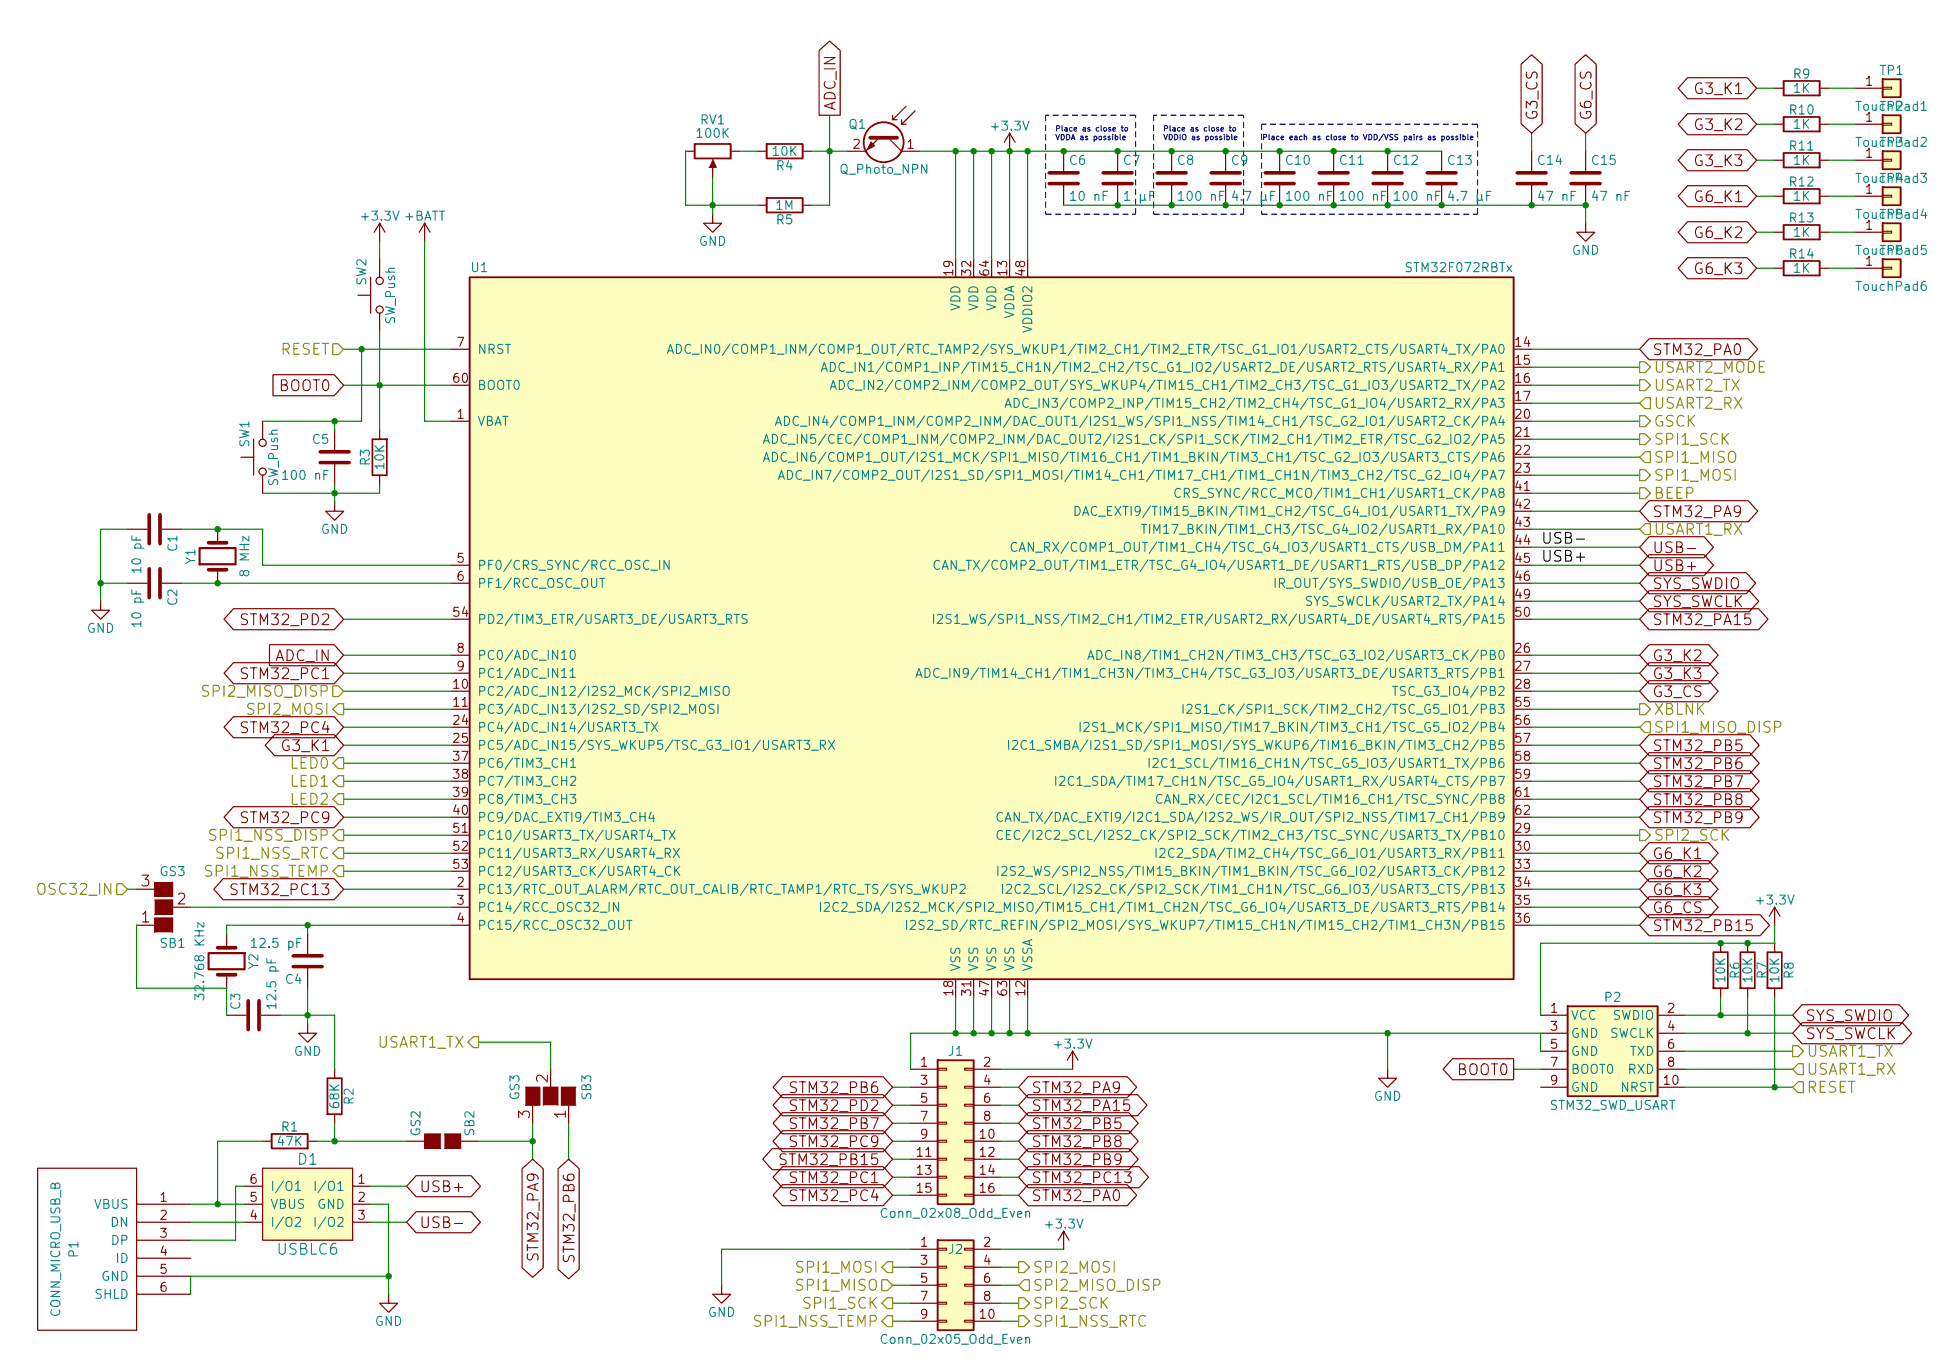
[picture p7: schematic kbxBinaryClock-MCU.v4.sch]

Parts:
C1, C2: 10 pF; C_0805
C3, C4: 12.5 pF; C_0805
C5, C8, C10, C11, C12: 100 nF; C_0805
C6: 10 nF; C_0805
C7: 1 µF; C_0805
C9, C13: 4.7 µF; C_0805
C14, C15: 47 nF; C_0805
D1: USBLC6; SOT-23-6
J1: Conn_02x08_Odd_Even; Pin_Header_Straight_2x08_Pitch2.54mm
J2: Conn_02x05_Odd_Even; Pin_Header_Straight_2x05_Pitch2.54mm
P1: CONN_MICRO_USB_B; USB_Micro-B_Molex-105017-0001
P2: STM32_SWD_USART; Pin_Header_Straight_2x05_Pitch1.27mm_SMD; Part Number M50-3600542R
Q1: Q_Photo_NPN; LED_D5.0mm; Part Number TEPT5600
R1: 47K; R_0805
R2: 68K; R_0805
R3, R4, R6, R7, R8: 10K; R_0805
R5: 1M; R_0805
R9, R10, R11, R12, R13, R14: 1K; R_0805
RV1: 100K; Potentiometer_Trimmer_Vishay_TS53YJ; Part Number TC33X-2-104E
SB1, SB3: GS3
SB2: GS2
SW1, SW2: SW_Push; SW_SPST_KMR2; Part Number KMR221G LFS
TP1: TouchPad1
TP2: TouchPad2; TouchPad1
TP3: TouchPad3; TouchPad1
TP4: TouchPad4; TouchPad1
TP5: TouchPad5; TouchPad1
TP6: TouchPad6; TouchPad1
U1: STM32F072RBTx; LQFP-64_10x10mm_Pitch0.5mm
Y1: 8 MHz; Crystal_SMD_5032-4pin_5.0x3.2mm; Part Number ABM3B-8.000MHZ-10-1UT
Y2: 32.768 KHz; Crystal_SMD_3215-2pin_3.2x1.5mm; Part Number ECX-.327-CDX-1293

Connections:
+3V3: C6.1, C7.1, C8.1, C9.1, C10.1, C11.1, C12.1, C13.1, J1.2, J2.2, P2.1 (VCC), Q1.1 (C), R6.1, R7.1, R8.1, SW2.2, U1.13 (VDDA), U1.19 (VDD), U1.32 (VDD), U1.48 (VDDIO2), U1.64 (VDD); also elsewhere on the board
+BATT: U1.1 (VBAT); also elsewhere on the board
/Display/GSCK: U1.20 (ADC_IN4/COMP1_INM/COMP2_INM/DAC_OUT1/I2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); also elsewhere on the board
/Display/SPI1_MISO_DISP: U1.56 (I2S1_MCK/SPI1_MISO/TIM17_BKIN/TIM3_CH1/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); also elsewhere on the board
/Display/SPI1_MOSI: J2.3, U1.23 (ADC_IN7/COMP2_OUT/I2S1_SD/SPI1_MOSI/TIM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); also elsewhere on the board
/Display/SPI1_NSS_DISP: U1.51 (PC10/USART3_TX/USART4_TX); also elsewhere on the board
/Display/SPI1_SCK: J2.7, U1.21 (ADC_IN5/CEC/COMP1_INM/COMP2_INM/DAC_OUT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); also elsewhere on the board
/Display/SPI2_MISO_DISP: J2.6, U1.10 (PC2/ADC_IN12/I2S2_MCK/SPI2_MISO); also elsewhere on the board
/Display/SPI2_MOSI: J2.4, U1.11 (PC3/ADC_IN13/I2S2_SD/SPI2_MOSI); also elsewhere on the board
/Display/SPI2_SCK: J2.8, U1.29 (CEC/I2C2_SCL/I2S2_CK/SPI2_SCK/TIM2_CH3/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); also elsewhere on the board
/Display/XBLNK: U1.55 (I2S1_CK/SPI1_SCK/TIM2_CH2/TSC_G5_IO1/PB3); also elsewhere on the board
/MCU/BEEP: U1.41 (CRS_SYNC/RCC_MCO/TIM1_CH1/USART1_CK/PA8); also elsewhere on the board
/MCU/LED0: U1.37 (PC6/TIM3_CH1); also elsewhere on the board
/MCU/LED1: U1.38 (PC7/TIM3_CH2); also elsewhere on the board
/MCU/LED2: U1.39 (PC8/TIM3_CH3); also elsewhere on the board
/MCU/OSC32_IN: SB1.3 (G3); also elsewhere on the board
/MCU/RESET: C5.1, P2.10 (NRST), R8.2, SW1.2, U1.7 (NRST); also elsewhere on the board
/MCU/SPI1_MISO: J2.5, U1.22 (ADC_IN6/COMP1_OUT/I2S1_MCK/SPI1_MISO/TI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); also elsewhere on the board
/MCU/SPI1_NSS_RTC: J2.10, U1.52 (PC11/USART3_RX/USART4_RX); also elsewhere on the board
/MCU/SPI1_NSS_TEMP: J2.9, U1.53 (PC12/USART3_CK/USART4_CK); also elsewhere on the board
/MCU/USART1_RX: P2.8 (RXD), U1.43 (TIM17_BKIN/TIM1_CH3/TSC_G4_IO2/USART1_R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); also elsewhere on the board
/MCU/USART1_TX: P2.6 (TXD), SB3.2 (G2); also elsewhere on the board
/MCU/USART2_MODE: U1.15 (ADC_IN1/COMP1_INP/TIM15_CH1N/TIM2_CH2/T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); also elsewhere on the board
/MCU/USART2_RX: U1.17 (ADC_IN3/COMP2_INP/TIM15_CH2/TIM2_CH4/TS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); also elsewhere on the board
/MCU/USART2_TX: U1.16 (ADC_IN2/COMP2_INM/COMP2_OUT/SYS_WKUP4/T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); also elsewhere on the board
ADC_IN: Q1.2 (E), R4.1, R5.1, U1.8 (PC0/ADC_IN10)
BOOT0: P2.7 (BOOT0), R3.2, SW2.1, U1.60 (BOOT0)
G3_CS: C14.1, U1.28 (TSC_G3_IO4/PB2)
G3_K1: R9.1, U1.25 (PC5/ADC_IN15/SYS_WKUP5/TSC_G3_IO1/USART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)
G3_K2: R10.1, U1.26 (ADC_IN8/TIM1_CH2N/TIM3_CH3/TSC_G3_IO2/U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)
G3_K3: R11.1, U1.27 (ADC_IN9/TIM14_CH1/TIM1_CH3N/TIM3_CH4/TS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)
G6_CS: C15.1, U1.35 (I2C2_SDA/I2S2_MCK/SPI2_MISO/TIM15_CH1/T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)
G6_K1: R12.1, U1.30 (I2C2_SDA/TIM2_CH4/TSC_G6_IO1/USART3_RX/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)
G6_K2: R13.1, U1.33 (I2S2_WS/SPI2_NSS/TIM15_BKIN/TIM1_BKIN/T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)
G6_K3: R14.1, U1.34 (I2C2_SCL/I2S2_CK/SPI2_SCK/TIM1_CH1N/TSC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)
GND: C1.2, C2.2, C3.2, C4.1, C5.2, C6.2, C7.2, C8.2, C9.2, C10.2, C11.2, C12.2, C13.2, C14.2, C15.2, D1.2 (GND), J1.1, J2.1, P1.5 (GND), P1.6 (SHLD), P2.3 (GND), P2.5 (GND), R2.1, R3.1, R5.2, RV1.2, RV1.3, SW1.1, U1.12 (VSSA), U1.18 (VSS), U1.31 (VSS), U1.47 (VSS), U1.63 (VSS); also elsewhere on the board
unnamed: C1.1, U1.5 (PF0/CRS_SYNC/RCC_OSC_IN), Y1.2
unnamed: C2.1, U1.6 (PF1/RCC_OSC_OUT), Y1.1
unnamed: C3.1, SB1.1 (G1), Y2.2
unnamed: C4.2, U1.4 (PC15/RCC_OSC32_OUT), Y2.1
unnamed: D1.4 (I/O2), P1.2 (DN)
unnamed: D1.5 (VBUS), P1.1 (VBUS), R1.1
unnamed: D1.6 (I/O1), P1.3 (DP)
unnamed: R1.2, R2.2, SB2.2 (G2)
unnamed: R4.2, RV1.1
unnamed: R9.2, TP1.1
unnamed: R10.2, TP2.1
unnamed: R11.2, TP3.1
unnamed: R12.2, TP4.1
unnamed: R13.2, TP5.1
unnamed: R14.2, TP6.1
unnamed: SB1.2 (G2), U1.3 (PC14/RCC_OSC32_IN)
STM32_PA0: J1.16, U1.14 (ADC_IN0/COMP1_INM/COMP1_OUT/RTC_TAMP2/S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)
STM32_PA9: J1.4, SB2.1 (G1), SB3.3 (G3), U1.42 (DAC_EXTI9/TIM15_BKIN/TIM1_CH2/TSC_G4_IO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)
STM32_PA15: J1.6, U1.50 (I2S1_WS/SPI1_NSS/TIM2_CH1/TIM2_ETR/USAR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)
STM32_PB5: J1.8, U1.57 (I2C1_SMBA/I2S1_SD/SPI1_MOSI/SYS_WKUP6/T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)
STM32_PB6: J1.3, SB3.1 (G1), U1.58 (I2C1_SCL/TIM16_CH1N/TSC_G5_IO3/USART1_T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)
STM32_PB7: J1.7, U1.59 (I2C1_SDA/TIM17_CH1N/TSC_G5_IO4/USART1_R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)
STM32_PB8: J1.10, U1.61 (CAN_RX/CEC/I2C1_SCL/TIM16_CH1/TSC_SYNC/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)
STM32_PB9: J1.12, U1.62 (CAN_TX/DAC_EXTI9/I2C1_SDA/I2S2_WS/IR_OU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)
STM32_PB15: J1.11, U1.36 (I2S2_SD/RTC_REFIN/SPI2_MOSI/SYS_WKUP7/T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)
STM32_PC1: J1.13, U1.9 (PC1/ADC_IN11)
STM32_PC4: J1.15, U1.24 (PC4/ADC_IN14/USART3_TX)
STM32_PC9: J1.9, U1.40 (PC9/DAC_EXTI9/TIM3_CH4)
STM32_PC13: J1.14, U1.2 (PC13/RTC_OUT_ALARM/RTC_OUT_CALIB/RTC_TA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)
STM32_PD2: J1.5, U1.54 (PD2/TIM3_ETR/USART3_DE/USART3_RTS)
SYS_SWCLK: P2.4 (SWCLK), R7.2, U1.49 (SYS_SWCLK/USART2_TX/PA14)
SYS_SWDIO: P2.2 (SWDIO), R6.2, U1.46 (IR_OUT/SYS_SWDIO/USB_OE/PA13)
USB+: D1.1 (I/O1), U1.45 (CAN_TX/COMP2_OUT/TIM1_ETR/TSC_G4_IO4/US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)
USB-: D1.3 (I/O2), U1.44 (CAN_RX/COMP1_OUT/TIM1_CH4/TSC_G4_IO3/US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)

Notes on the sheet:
Place as close to VDDA as possible
Place as close to VDDIO as possible
Place each as close to VDD/VSS pairs as possible

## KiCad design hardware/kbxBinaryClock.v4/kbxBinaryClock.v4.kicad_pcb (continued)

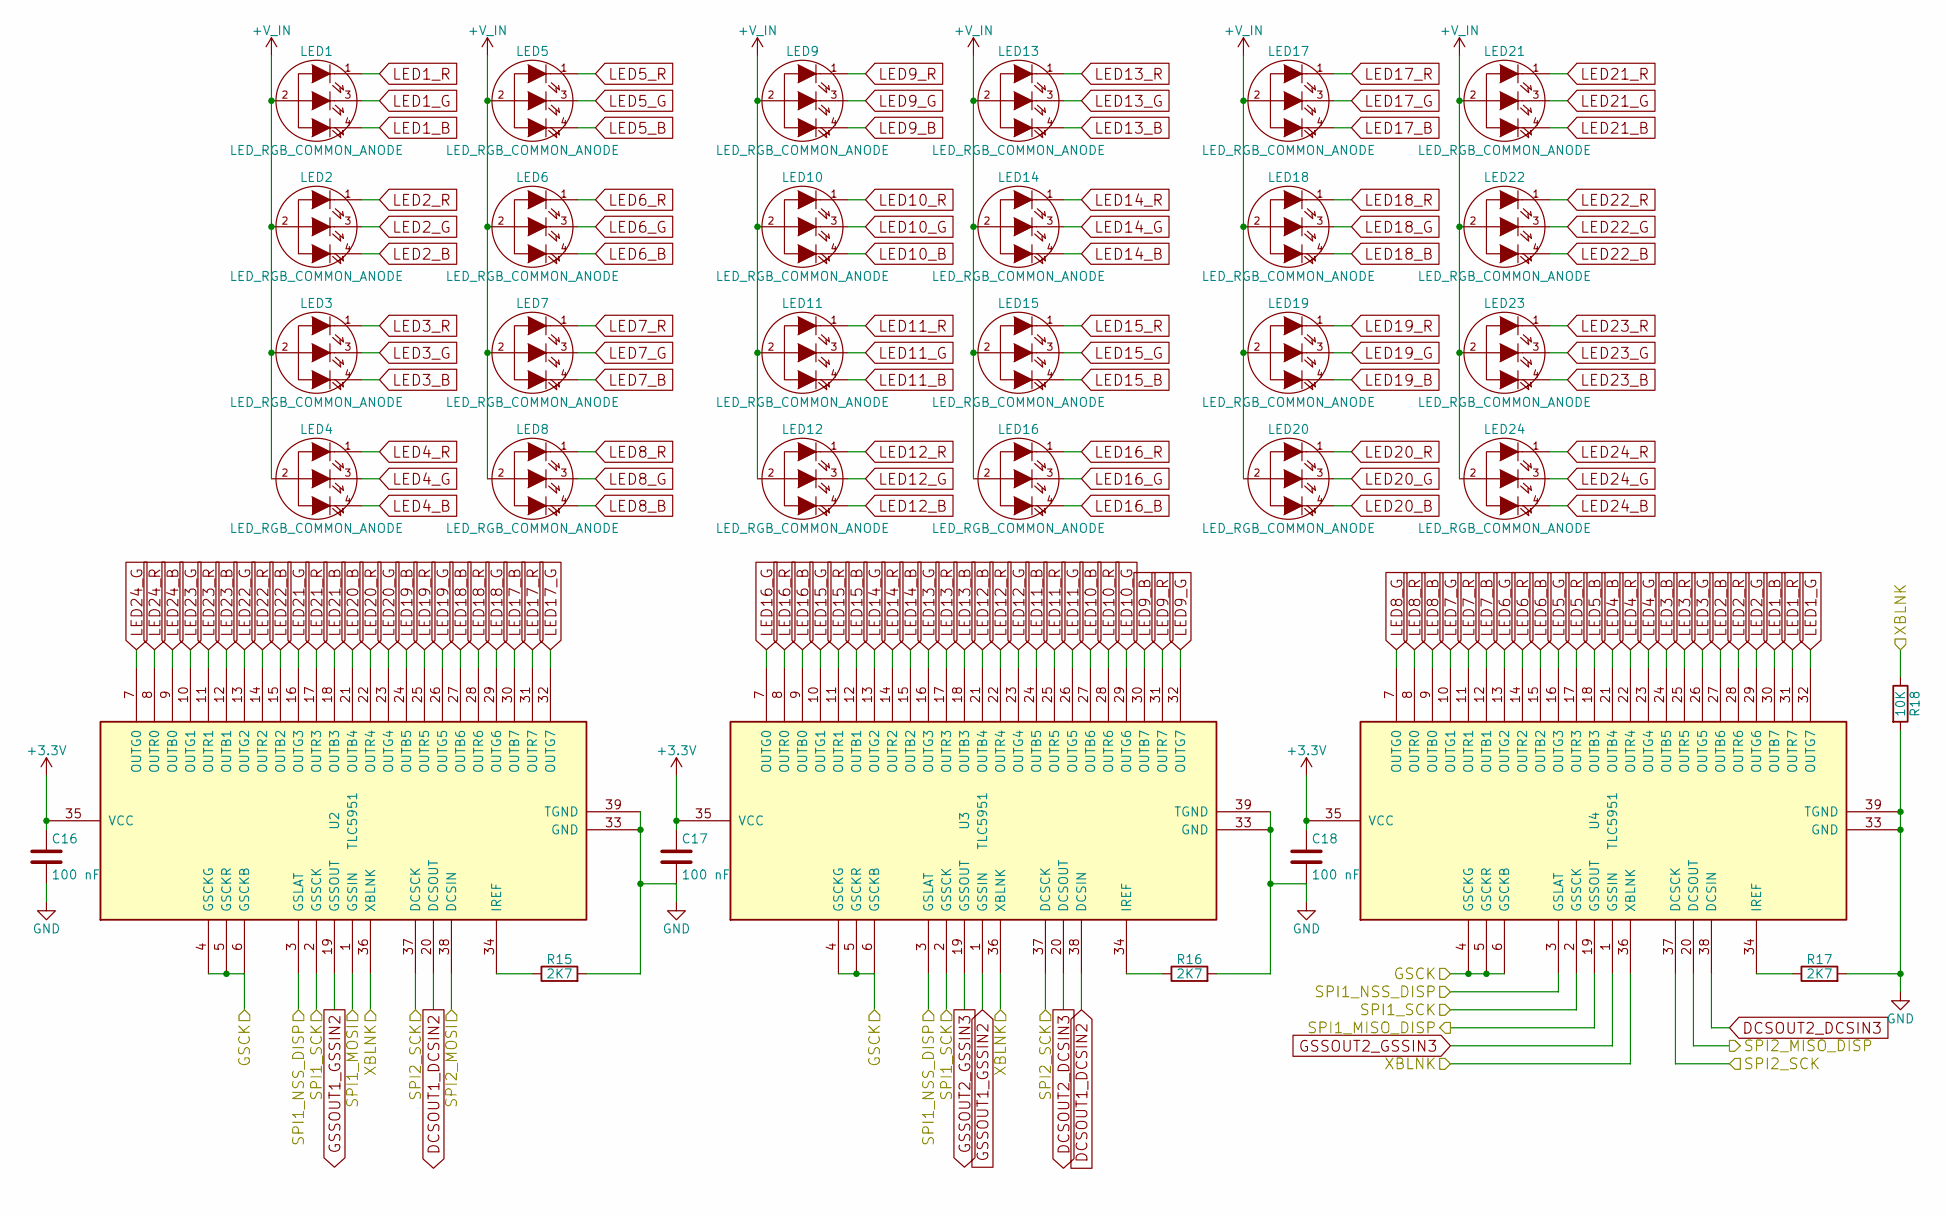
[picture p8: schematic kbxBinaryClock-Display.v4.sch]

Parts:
C16, C17, C18: 100 nF; C_0805
LED1, LED2, LED3, LED4, LED5, LED6, LED7, LED8, LED9, LED10, LED11, LED12, LED13, LED14, LED15, LED16, LED17, LED18, LED19, LED20, LED21, LED22, LED23, LED24: LED_RGB_COMMON_ANODE; LED_D5.0mm-4
R15, R16, R17: 2K7; R_0805
R18: 10K; R_0805
U2, U3, U4: TLC5951; HTSSOP-38_6.1x12.5mm_Pitch0.65mm_ThermalPad

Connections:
+3V3: C16.1, C17.1, C18.1, U2.35 (VCC), U3.35 (VCC), U4.35 (VCC); also elsewhere on the board
+V_IN: LED1.2 (COMMON), LED2.2 (COMMON), LED3.2 (COMMON), LED4.2 (COMMON), LED5.2 (COMMON), LED6.2 (COMMON), LED7.2 (COMMON), LED8.2 (COMMON), LED9.2 (COMMON), LED10.2 (COMMON), LED11.2 (COMMON), LED12.2 (COMMON), LED13.2 (COMMON), LED14.2 (COMMON), LED15.2 (COMMON), LED16.2 (COMMON), LED17.2 (COMMON), LED18.2 (COMMON), LED19.2 (COMMON), LED20.2 (COMMON), LED21.2 (COMMON), LED22.2 (COMMON), LED23.2 (COMMON), LED24.2 (COMMON); also elsewhere on the board
/Display/GSCK: U2.4 (GSCKG), U2.5 (GSCKR), U2.6 (GSCKB), U3.4 (GSCKG), U3.5 (GSCKR), U3.6 (GSCKB), U4.4 (GSCKG), U4.5 (GSCKR), U4.6 (GSCKB); also elsewhere on the board
/Display/SPI1_MISO_DISP: U4.19 (GSSOUT); also elsewhere on the board
/Display/SPI1_MOSI: U2.1 (GSSIN); also elsewhere on the board
/Display/SPI1_NSS_DISP: U2.3 (GSLAT), U3.3 (GSLAT), U4.3 (GSLAT); also elsewhere on the board
/Display/SPI1_SCK: U2.2 (GSSCK), U3.2 (GSSCK), U4.2 (GSSCK); also elsewhere on the board
/Display/SPI2_MISO_DISP: U4.20 (DCSOUT); also elsewhere on the board
/Display/SPI2_MOSI: U2.38 (DCSIN); also elsewhere on the board
/Display/SPI2_SCK: U2.37 (DCSCK), U3.37 (DCSCK), U4.37 (DCSCK); also elsewhere on the board
/Display/XBLNK: R18.1, U2.36 (XBLNK), U3.36 (XBLNK), U4.36 (XBLNK); also elsewhere on the board
DCSOUT1_DCSIN2: U2.20 (DCSOUT), U3.38 (DCSIN)
DCSOUT2_DCSIN3: U3.20 (DCSOUT), U4.38 (DCSIN)
GND: C16.2, C17.2, C18.2, R15.2, R16.2, R17.2, R18.2, U2.33 (GND), U2.39 (TGND), U3.33 (GND), U3.39 (TGND), U4.33 (GND), U4.39 (TGND); also elsewhere on the board
GSSOUT1_GSSIN2: U2.19 (GSSOUT), U3.1 (GSSIN)
GSSOUT2_GSSIN3: U3.19 (GSSOUT), U4.1 (GSSIN)
LED1_B: LED1.4 (BLUE), U4.30 (OUTB7)
LED1_G: LED1.3 (GREEN), U4.32 (OUTG7)
LED1_R: LED1.1 (RED), U4.31 (OUTR7)
LED2_B: LED2.4 (BLUE), U4.27 (OUTB6)
LED2_G: LED2.3 (GREEN), U4.29 (OUTG6)
LED2_R: LED2.1 (RED), U4.28 (OUTR6)
LED3_B: LED3.4 (BLUE), U4.24 (OUTB5)
LED3_G: LED3.3 (GREEN), U4.26 (OUTG5)
LED3_R: LED3.1 (RED), U4.25 (OUTR5)
LED4_B: LED4.4 (BLUE), U4.21 (OUTB4)
LED4_G: LED4.3 (GREEN), U4.23 (OUTG4)
LED4_R: LED4.1 (RED), U4.22 (OUTR4)
LED5_B: LED5.4 (BLUE), U4.18 (OUTB3)
LED5_G: LED5.3 (GREEN), U4.16 (OUTG3)
LED5_R: LED5.1 (RED), U4.17 (OUTR3)
LED6_B: LED6.4 (BLUE), U4.15 (OUTB2)
LED6_G: LED6.3 (GREEN), U4.13 (OUTG2)
LED6_R: LED6.1 (RED), U4.14 (OUTR2)
LED7_B: LED7.4 (BLUE), U4.12 (OUTB1)
LED7_G: LED7.3 (GREEN), U4.10 (OUTG1)
LED7_R: LED7.1 (RED), U4.11 (OUTR1)
LED8_B: LED8.4 (BLUE), U4.9 (OUTB0)
LED8_G: LED8.3 (GREEN), U4.7 (OUTG0)
LED8_R: LED8.1 (RED), U4.8 (OUTR0)
LED9_B: LED9.4 (BLUE), U3.30 (OUTB7)
LED9_G: LED9.3 (GREEN), U3.32 (OUTG7)
LED9_R: LED9.1 (RED), U3.31 (OUTR7)
LED10_B: LED10.4 (BLUE), U3.27 (OUTB6)
LED10_G: LED10.3 (GREEN), U3.29 (OUTG6)
LED10_R: LED10.1 (RED), U3.28 (OUTR6)
LED11_B: LED11.4 (BLUE), U3.24 (OUTB5)
LED11_G: LED11.3 (GREEN), U3.26 (OUTG5)
LED11_R: LED11.1 (RED), U3.25 (OUTR5)
LED12_B: LED12.4 (BLUE), U3.21 (OUTB4)
LED12_G: LED12.3 (GREEN), U3.23 (OUTG4)
LED12_R: LED12.1 (RED), U3.22 (OUTR4)
LED13_B: LED13.4 (BLUE), U3.18 (OUTB3)
LED13_G: LED13.3 (GREEN), U3.16 (OUTG3)
LED13_R: LED13.1 (RED), U3.17 (OUTR3)
LED14_B: LED14.4 (BLUE), U3.15 (OUTB2)
LED14_G: LED14.3 (GREEN), U3.13 (OUTG2)
LED14_R: LED14.1 (RED), U3.14 (OUTR2)
LED15_B: LED15.4 (BLUE), U3.12 (OUTB1)
LED15_G: LED15.3 (GREEN), U3.10 (OUTG1)
LED15_R: LED15.1 (RED), U3.11 (OUTR1)
LED16_B: LED16.4 (BLUE), U3.9 (OUTB0)
LED16_G: LED16.3 (GREEN), U3.7 (OUTG0)
LED16_R: LED16.1 (RED), U3.8 (OUTR0)
LED17_B: LED17.4 (BLUE), U2.30 (OUTB7)
LED17_G: LED17.3 (GREEN), U2.32 (OUTG7)
LED17_R: LED17.1 (RED), U2.31 (OUTR7)
LED18_B: LED18.4 (BLUE), U2.27 (OUTB6)
LED18_G: LED18.3 (GREEN), U2.29 (OUTG6)
LED18_R: LED18.1 (RED), U2.28 (OUTR6)
LED19_B: LED19.4 (BLUE), U2.24 (OUTB5)
LED19_G: LED19.3 (GREEN), U2.26 (OUTG5)
LED19_R: LED19.1 (RED), U2.25 (OUTR5)
LED20_B: LED20.4 (BLUE), U2.21 (OUTB4)
LED20_G: LED20.3 (GREEN), U2.23 (OUTG4)
LED20_R: LED20.1 (RED), U2.22 (OUTR4)
LED21_B: LED21.4 (BLUE), U2.18 (OUTB3)
LED21_G: LED21.3 (GREEN), U2.16 (OUTG3)
LED21_R: LED21.1 (RED), U2.17 (OUTR3)
LED22_B: LED22.4 (BLUE), U2.15 (OUTB2)
LED22_G: LED22.3 (GREEN), U2.13 (OUTG2)
LED22_R: LED22.1 (RED), U2.14 (OUTR2)
LED23_B: LED23.4 (BLUE), U2.12 (OUTB1)
LED23_G: LED23.3 (GREEN), U2.10 (OUTG1)
LED23_R: LED23.1 (RED), U2.11 (OUTR1)
LED24_B: LED24.4 (BLUE), U2.9 (OUTB0)
LED24_G: LED24.3 (GREEN), U2.7 (OUTG0)
LED24_R: LED24.1 (RED), U2.8 (OUTR0)
unnamed: R15.1, U2.34 (IREF)
unnamed: R16.1, U3.34 (IREF)
unnamed: R17.1, U4.34 (IREF)

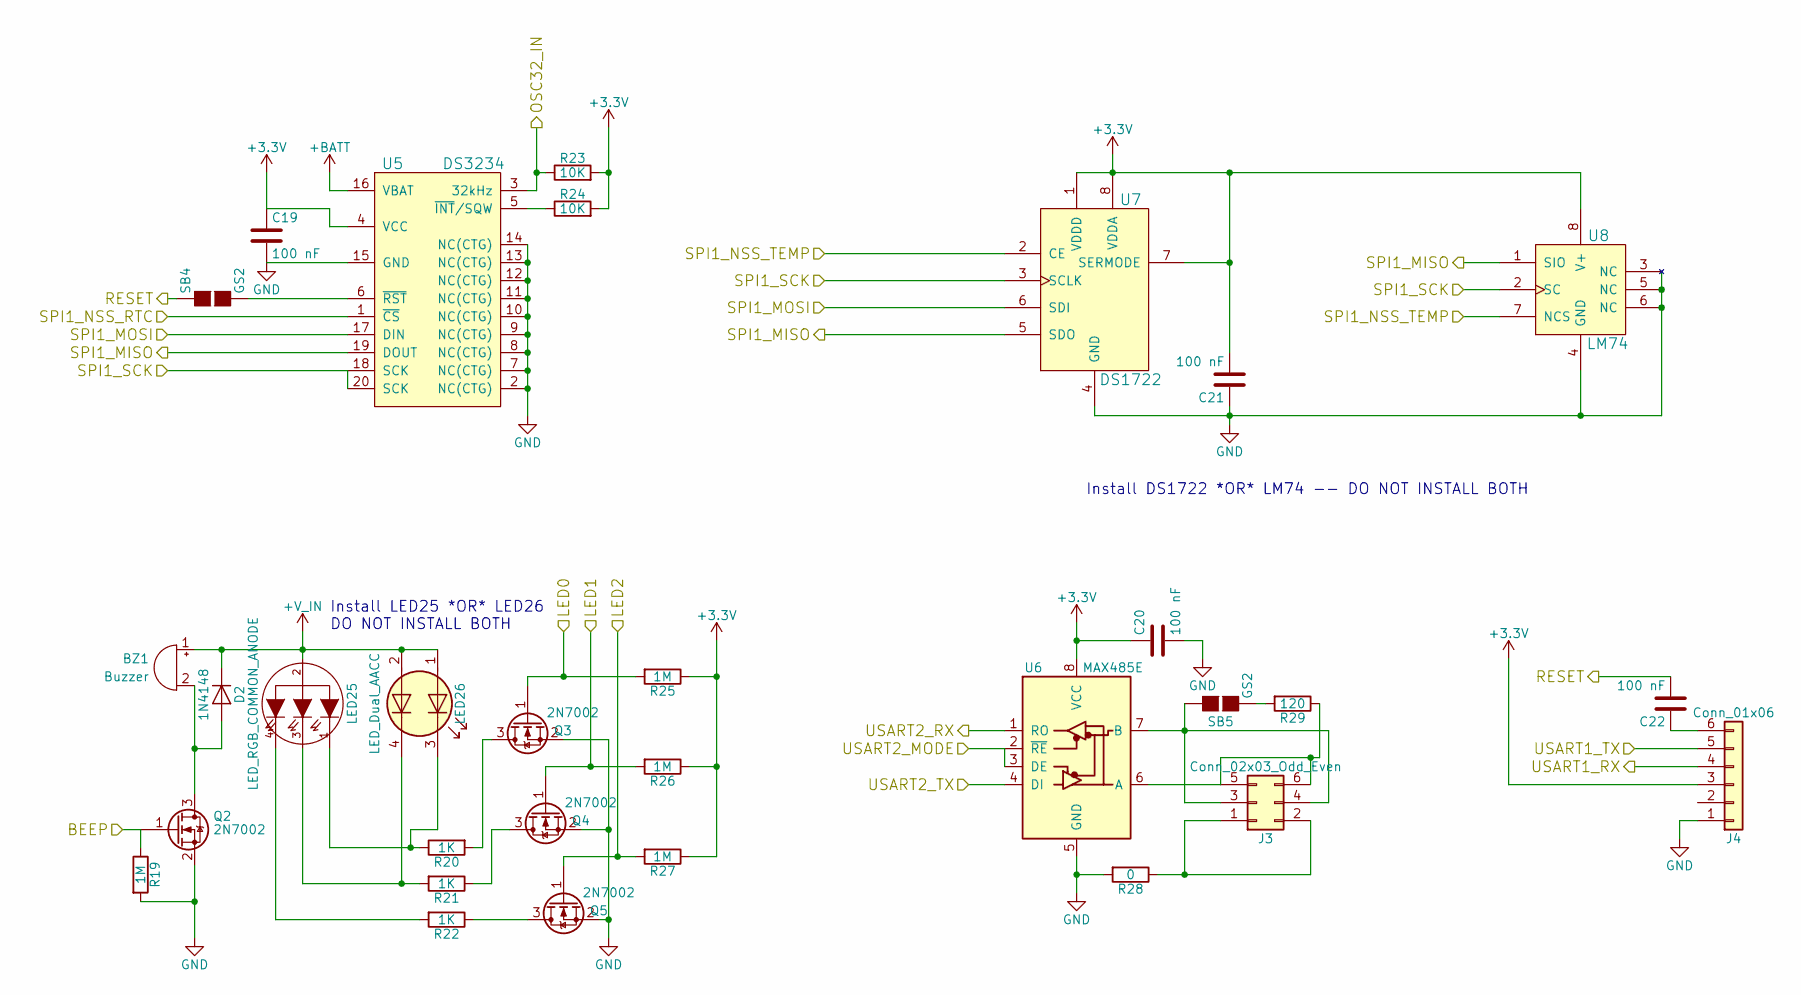
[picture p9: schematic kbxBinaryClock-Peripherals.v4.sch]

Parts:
BZ1: Buzzer; Buzzer_12x9.5RM7.6; Part Number TDK SD1614TT-B1
C19, C20, C21, C22: 100 nF; C_0805
D2: 1N4148; D_SOD-123
J3: Conn_02x03_Odd_Even; Pin_Header_Straight_2x03_Pitch2.54mm
J4: Conn_01x06; Pin_Header_Straight_1x06_Pitch2.54mm
LED25: LED_RGB_COMMON_ANODE; LED_D5.0mm-4
LED26: LED_Dual_AACC; LED_Cree-PLCC4_3.2x2.8mm_CCW; Part Number CMD1522SRUGCTR8
Q2, Q3, Q4, Q5: 2N7002; SOT-23
R19, R25, R26, R27: 1M; R_0805
R20, R21, R22: 1K; R_0805
R23, R24: 10K; R_0805
R28: 0; R_0805
R29: 120; R_0805
SB4, SB5: GS2
U5: DS3234; SO-20_12.8x7.5mm_Pitch1.27mm
U6: MAX485E; SOIC-8_3.9x4.9mm_Pitch1.27mm; Part Number ST1480ACDR
U7: DS1722; SOIC-8_3.9x4.9mm_Pitch1.27mm
U8: LM74; SOIC-8_3.9x4.9mm_Pitch1.27mm; Part Number LM74CIMX-3/NOPB

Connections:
+3V3: C19.1, C20.1, C21.2, J4.3, R23.2, R24.2, R25.1, R26.1, R27.1, U5.4 (VCC), U6.8 (VCC), U7.1 (VDDD), U7.7 (SERMODE), U7.8 (VDDA), U8.8 (V+); also elsewhere on the board
+BATT: U5.16 (VBAT); also elsewhere on the board
+V_IN: BZ1.1 (-), D2.1 (K), LED25.2 (COMMON), LED26.1 (A1), LED26.2 (A2); also elsewhere on the board
/Display/SPI1_MOSI: U5.17 (DIN), U7.6 (SDI); also elsewhere on the board
/Display/SPI1_SCK: U5.18 (SCK), U5.20 (SCK), U7.3 (SCLK), U8.2 (SC); also elsewhere on the board
/MCU/BEEP: Q2.1 (G), R19.1; also elsewhere on the board
/MCU/LED0: Q3.1 (G), R25.2; also elsewhere on the board
/MCU/LED1: Q4.1 (G), R26.2; also elsewhere on the board
/MCU/LED2: Q5.1 (G), R27.2; also elsewhere on the board
/MCU/OSC32_IN: R23.1, U5.3 (32kHz); also elsewhere on the board
/MCU/RESET: C22.2, SB4.1 (G1); also elsewhere on the board
/MCU/SPI1_MISO: U5.19 (DOUT), U7.5 (SDO), U8.1 (SIO); also elsewhere on the board
/MCU/SPI1_NSS_RTC: U5.1 (~CS~); also elsewhere on the board
/MCU/SPI1_NSS_TEMP: U7.2 (CE), U8.7 (NCS); also elsewhere on the board
/MCU/USART1_RX: J4.4; also elsewhere on the board
/MCU/USART1_TX: J4.5; also elsewhere on the board
/MCU/USART2_MODE: U6.2 (~RE), U6.3 (DE); also elsewhere on the board
/MCU/USART2_RX: U6.1 (RO); also elsewhere on the board
/MCU/USART2_TX: U6.4 (DI); also elsewhere on the board
GND: C19.2, C20.2, C21.1, J4.1, Q2.2 (S), Q3.2 (S), Q4.2 (S), Q5.2 (S), R19.2, R28.2, U5.2 (NC(CTG)), U5.7 (NC(CTG)), U5.8 (NC(CTG)), U5.9 (NC(CTG)), U5.10 (NC(CTG)), U5.11 (NC(CTG)), U5.12 (NC(CTG)), U5.13 (NC(CTG)), U5.14 (NC(CTG)), U5.15 (GND), U6.5 (GND), U7.4 (GND), U8.3 (NC), U8.4 (GND), U8.5 (NC), U8.6 (NC); also elsewhere on the board
unnamed: BZ1.2 (+), D2.2 (A), Q2.3 (D)
unnamed: C22.1, J4.6
unnamed: J3.1, J3.2, R28.1
unnamed: J3.3, J3.4, SB5.1 (G1), U6.7 (B)
unnamed: J3.5, J3.6, R29.1, U6.6 (A)
unnamed: LED25.1 (RED), LED26.3 (K1), R20.1
unnamed: LED25.3 (GREEN), LED26.4 (K2), R21.2
unnamed: LED25.4 (BLUE), R22.2
unnamed: Q3.3 (D), R20.2
unnamed: Q4.3 (D), R21.1
unnamed: Q5.3 (D), R22.1
unnamed: R24.1, U5.5 (~INT~/SQW)
unnamed: R29.2, SB5.2 (G2)
unnamed: SB4.2 (G2), U5.6 (~RST~)

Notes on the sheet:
Install DS1722 *OR* LM74 -- DO NOT INSTALL BOTH
Install LED25 *OR* LED26 DO NOT INSTALL BOTH

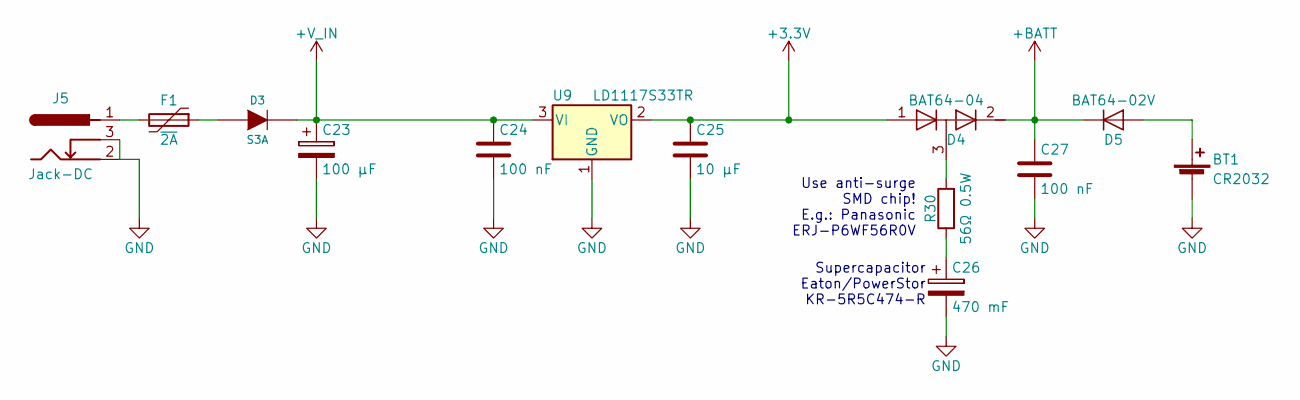
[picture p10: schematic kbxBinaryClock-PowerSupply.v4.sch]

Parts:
BT1: CR2032; Keystone_103_1x20mm-CoinCell; Part Number 103
C23: 100 µF; CP_Elec_8x10; Part Number 25SVF100M
C24, C27: 100 nF; C_0805
C25: 10 µF; C_0805
C26: 470 mF; CP_Radial_D13.0mm_P5.00mm_HD1.5mm; Part Number KR-5R5H474-R
D3: S3A; D_SMC; Part Number S3A
D4: BAT64-04; SOT-23
D5: BAT64-02V; D_0603
F1: ~2A; Fuse_SMD2920; Part Number 2920L185DR
J5: Jack-DC; BARREL_JACK
R30: 56Ω 0.5W; R_0805
U9: LD1117S33TR; TO-252-2; Part Number LD1117ADT33TR

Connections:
+3V3: C25.1, D4.1 (A), U9.2 (VO); also elsewhere on the board
+BATT: C27.1, D4.2 (K), D5.1 (K); also elsewhere on the board
+V_IN: C23.1, C24.1, D3.2 (K), U9.3 (VI); also elsewhere on the board
GND: BT1.2 (-), C23.2, C24.2, C25.2, C26.2, C27.2, J5.2, J5.3, U9.1 (GND); also elsewhere on the board
unnamed: BT1.1 (+), D5.2 (A)
unnamed: C26.1, R30.1
unnamed: D3.1 (A), F1.1
unnamed: D4.3 (common), R30.2
unnamed: F1.2, J5.1

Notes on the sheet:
Supercapacitor Eaton/PowerStor KR-5R5C474-R
Use anti-surge SMD chip! E.g.: Panasonic ERJ-P6WF56R0V

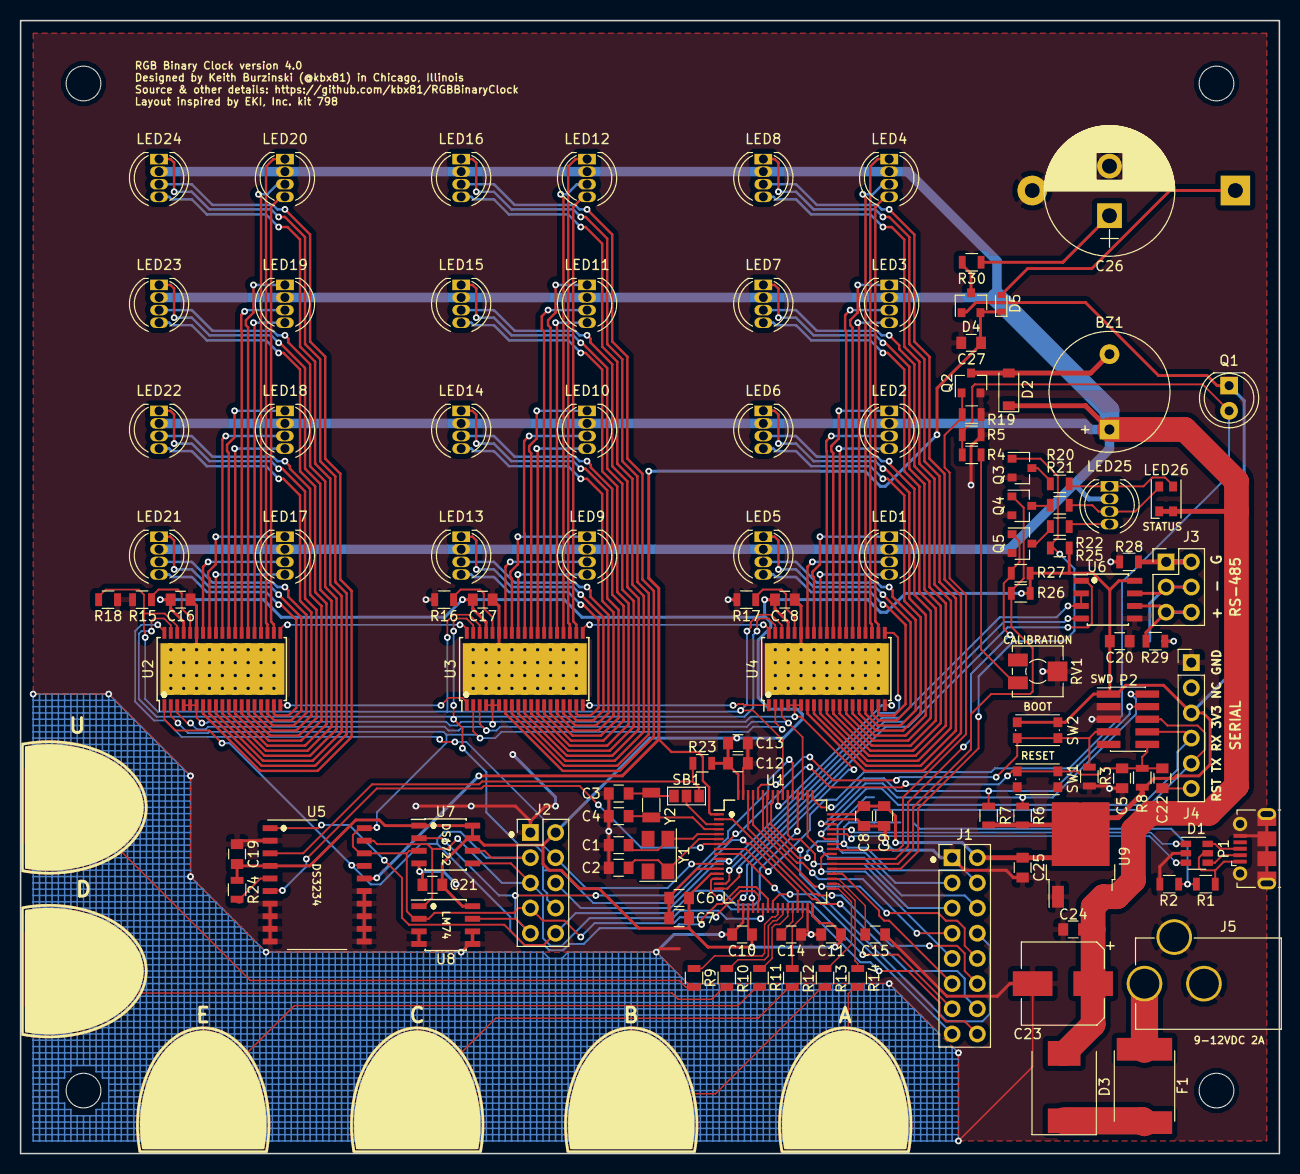
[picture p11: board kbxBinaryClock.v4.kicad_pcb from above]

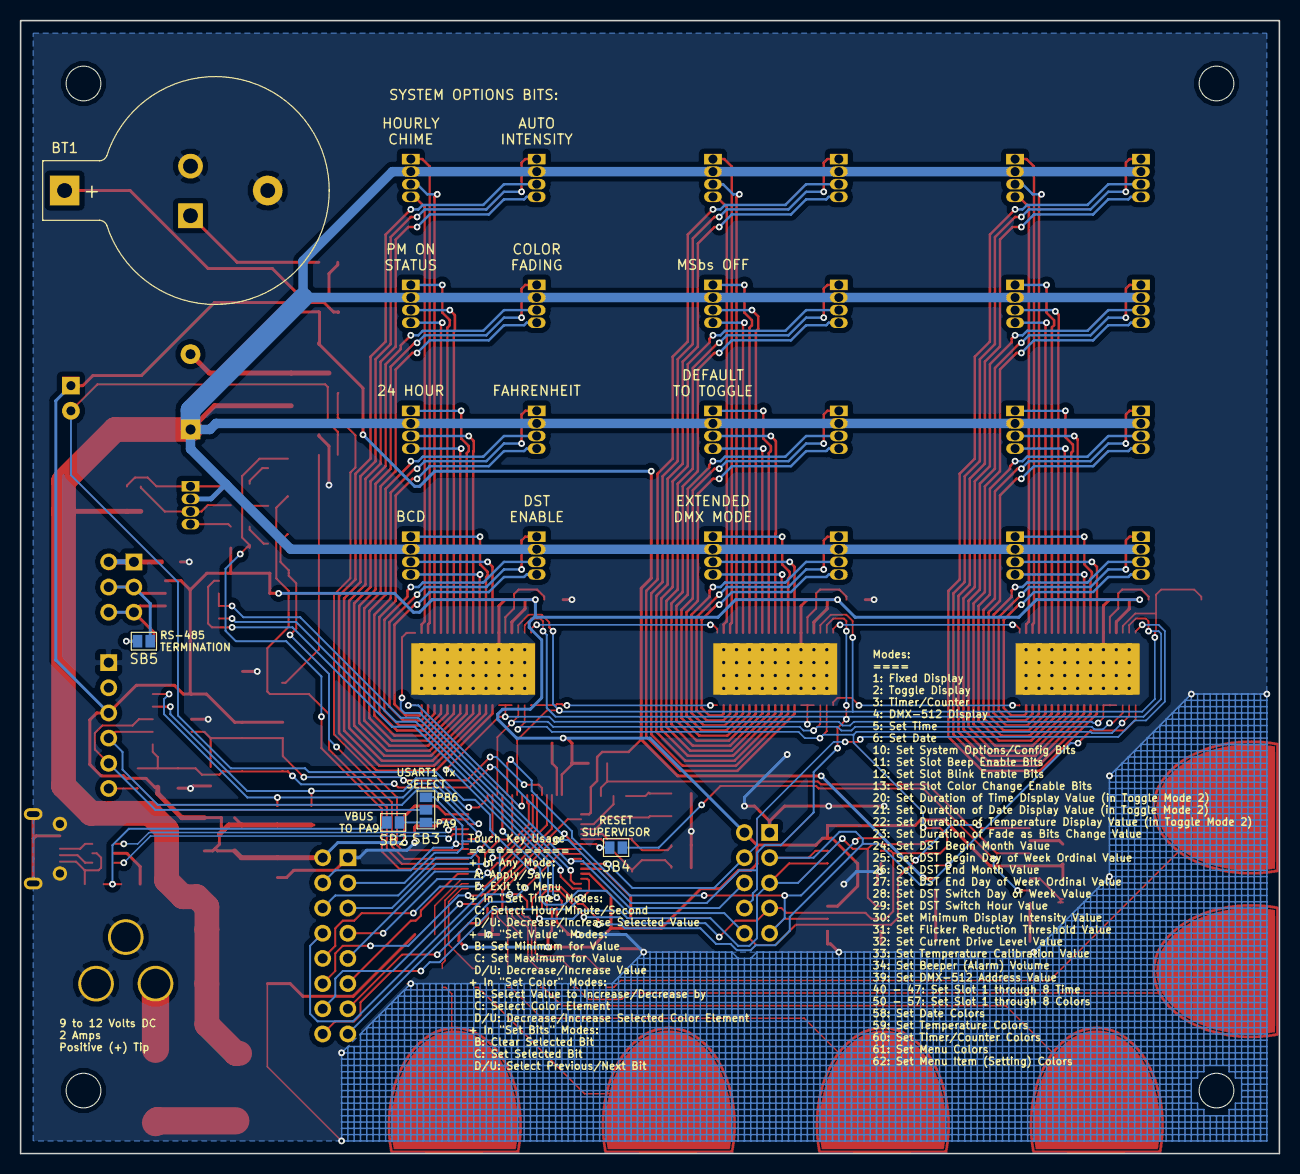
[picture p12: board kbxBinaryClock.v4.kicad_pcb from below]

Board: 2 copper layers, 127.0 x 114.3 mm, 132 parts (5 on the bottom side), 169 nets.

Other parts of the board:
MH1, MH2, MH3, MH4: MountingHole_3.5mm

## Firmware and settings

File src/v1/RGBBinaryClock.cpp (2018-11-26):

//
// kbx81's binary clock
// ---------------------------------------------------------------------------
// (c)2017 by kbx81. See LICENSE for details.
//
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

#include <libopencm3/cm3/nvic.h>
#include "Hardware.h"
#include "Application.h"
#include "DisplayManager.h"
#include "Dmx-512-Controller.h"
#include "Dmx-512-Rx.h"
#include "Keys.h"


using namespace kbxBinaryClock;


/* ADC DMA */
void dma1_channel1_isr(void)
{
	Hardware::dmaIsr();
}


/* SPI receive completed with DMA */
void dma1_channel2_3_isr(void)
{
	Hardware::dmaIsr();
}


/* I2C and USART transmit/receive completed with DMA */
void dma1_channel4_5_isr()
{
	Hardware::dmaIsr();
}


/* Called when systick fires */
void sys_tick_handler(void)
{
	Hardware::systickIsr();
	Keys::repeatHandler();
  Dmx512Controller::strobeTimer();
  DisplayManager::tick();
	Application::tick();
}


/* Timer 2 interrupt -- used for triggering LED driver latches */
void tim2_isr()
{
  Hardware::tim2Isr();
}


/* Timer 15 interrupt -- used for DMX-512 break length measurement */
void tim15_isr()
{
  Hardware::tim15Isr();
	Dmx512Rx::timerUartIsr();
}


/* Timer 16 interrupt -- used for DMX-512 signal monitoring */
void tim16_isr()
{
  Hardware::tim16Isr();
	Dmx512Rx::timerSupervisorIsr();
}


/* TSC */
void tsc_isr(void)
{
	Hardware::tscIsr();
}


/* USART1 */
void usart1_isr(void)
{
	Hardware::usart1Isr();
}


/* USART1 */
void usart2_isr(void)
{
	Hardware::usart2Isr();
	Dmx512Rx::rxIsr();
}


/* Where all life begins...more or less */
int main()
{
	Hardware::initialize();

  Application::initialize();

  Application::loop();
}

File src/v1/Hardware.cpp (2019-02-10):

//
// kbx81's binary clock Hardware class
// ---------------------------------------------------------------------------
// (c)2017 by kbx81. See LICENSE for details.
//
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

// #include <cstddef>
#include <cstdint>
// #include <errno.h>
// #include <stdio.h>
// #include <stdlib.h>
// #include <string.h>
#include <libopencm3/cm3/nvic.h>
#include <libopencm3/cm3/systick.h>
#include <libopencm3/stm32/adc.h>
#include <libopencm3/stm32/crc.h>
#include <libopencm3/stm32/dma.h>
#include <libopencm3/stm32/flash.h>
#include <libopencm3/stm32/gpio.h>
#include <libopencm3/stm32/i2c.h>
#include <libopencm3/stm32/iwdg.h>
#include <libopencm3/stm32/pwr.h>
#include <libopencm3/stm32/rcc.h>
#include <libopencm3/stm32/rtc.h>
#include <libopencm3/stm32/spi.h>
#include <libopencm3/stm32/syscfg.h>
#include <libopencm3/stm32/timer.h>
#include <libopencm3/stm32/tsc.h>
#include <libopencm3/stm32/usart.h>

#include "Application.h"
#include "DateTime.h"
#include "Display.h"
#include "DisplayManager.h"
#include "Dmx-512-Rx.h"
#include "DS1722.h"
#include "DS3231.h"
#include "DS3234.h"
#include "Hardware.h"
#include "LM74.h"
#include "LM75.h"
#include "MCP9808.h"
#include "RgbLed.h"
#include "TLC59xx.h"

#if HARDWARE_VERSION == 1
  #include "Hardware_v1.h"
#elif HARDWARE_VERSION == 2
  #include "Hardware_v2.h"
#elif HARDWARE_VERSION == 3
  #include "Hardware_v3.h"
#elif HARDWARE_VERSION == 4
  #include "Hardware_v4.h"
#else
  #error HARDWARE_VERSION must be defined with a value between 1 and 4
#endif


namespace kbxBinaryClock {

namespace Hardware {


  // Type of temperature sensor connected, if any
  //
  enum TempSensorType : uint8_t {
    None,
    DS3231,
    DS3234,
    DS1722,
    LM74,
    LM75,
    MCP9808
  };

  // I2C1 state
  //
  enum I2cState : uint8_t {
    I2cIdle,
    I2cBusy
  };

  // SPI1 state
  //
  enum SpiState : uint8_t {
    SpiIdle,
    SpiBusyPeripheral,
    SpiBusyDisplay
  };

  // LED driver shift register state
  //
  enum DriverShiftRegState : uint8_t {
    SrAvailable,
    SrLoadingGsData,
    SrLoadingOtherData,
    SrContainsGsData,
    SrContainsOtherData
  };


// USART baud rates
//
static const uint32_t cUsart1BaudRate = 115200;
static const uint32_t cUsart2BaudRate = 250000;

// number of ADC channels we're using
//
static const uint8_t cAdcChannelCount = 4;

// indexes of ADC channels we're DMA'ing into our buffer
//
static const uint8_t cAdcPhototransistor = 0;
static const uint8_t cAdcTemperature = 1;
static const uint8_t cAdcVref = 2;
static const uint8_t cAdcVbat = 3;

// how frequently we will sample things
//
static const uint16_t cAdcSampleInterval = 500;

// number of samples averaged for light level and temp
//
static const uint8_t cAdcSamplesToAverage = 16;

// value used to increase precision in our maths
//
static const int16_t cBaseMultiplier = 1000;

// the last page number in the flash memory
//
static const uint32_t cFlashPageNumberMaximum = 63;

// the last page number in the flash memory
//
static const uint32_t cFlashPageSize = 0x800;

// maximum time we'll wait for an ACK on I2C
//
static const uint16_t cI2cTimeout = 5000;

// maximum number of times we'll fail requests because I2C is busy
//
static const uint8_t cI2cMaxFailBusyCount = 20;

// value by which we multiply the fractional part of temperature sensor readings
//
static const int16_t cTempFracMultiplier = 125;

// minimum frequency allowed for tones
//
static const uint8_t cToneFrequencyMinimum = 92;

// maximum volume level allowed for tones
//
static const uint8_t cToneVolumeMaximum = 7;

// maximum minimum allowed to consider a key pressed/touched
//
static const uint16_t cTscMaximumMinimum = 1536;

// minimum required difference between min and max readings
//
static const uint16_t cTscMinimumDelta = 400;

// number of samples averaged for sensors
//
static const uint8_t cTscSamplesToAverage = 32;

// calibration voltage used (3.3 volts)
//
static const int32_t cVddCalibrationVoltage = 3300;


// tracks which array element the next sample is to be written to
//
static uint8_t _adcSampleCounter = 0;

// tracks when to take a sample
//
static uint16_t _adcSampleTimer = 0;

// samples averaged for light
//
static uint16_t _adcSampleSetLight[cAdcSamplesToAverage];

// samples averaged for temperature
//
static uint16_t _adcSampleSetTemp[cAdcSamplesToAverage];

// samples averaged for voltage
//
static uint16_t _adcSampleSetVoltage[cAdcSamplesToAverage];

// tracks what's going on with the LED drivers' shift registers
//
volatile static DriverShiftRegState _ledDriverSrState = DriverShiftRegState::SrAvailable;

// threshold above which we do not BLANK during display refreshes
//  used when autoAdjustIntensities is true
static uint16_t _blankingThreshold = 300;

// counter used by delay()
//
volatile static uint32_t _delayCounter = 0;

// a place for data from the ADC to live
//
static uint16_t _bufferADC[cAdcChannelCount];
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

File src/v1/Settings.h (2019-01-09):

//
// kbx81's binary clock settings class
// ---------------------------------------------------------------------------
// (c)2017 by kbx81. See LICENSE for details.
//
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
#pragma once


#include <cstdint>

#include "DateTime.h"
#include "Hardware.h"
#include "RgbLed.h"


namespace kbxBinaryClock {

class Settings {

public:

  /// @brief Types of settings we keep
  ///
  enum Setting : uint8_t
  {
    SystemOptions = 0,
    BeepStates = 1,
    BlinkStates = 2,
    ColorStates = 3,
    TimeDisplayDuration = 4,
    DateDisplayDuration = 5,
    TemperatureDisplayDuration = 6,
    FadeDuration = 7,
    DateFormat = 8,
    DstBeginMonth = 9,
    DstBeginDowOrdinal = 10,
    DstEndMonth = 11,
    DstEndDowOrdinal = 12,
    DstSwitchDayOfWeek = 13,
    DstSwitchHour = 14,
    MinimumIntensity = 15,
    FlickerReduction = 16,
    CurrentDrive = 17,
    TemperatureCalibration = 18,
    BeeperVolume = 19,
    TimerResetValue = 20,
    DisplayRefreshInterval = 21,
    DmxAddress = 22
  };

  /// @brief Settings we keep
  ///
  enum SystemOptionsBits : uint8_t
  {
    DisplayBCD = 0,
    Display12Hour = 1,
    StatusLedAsAmPm = 2,
    HourlyChime = 3,
    DstEnable = 4,
    DisplayFahrenheit = 5,
    FadeAcrossSlots = 6,
    AutoAdjustIntensity = 7,
    DmxExtended = 8,
    StartupToToggle = 9,
    MSBsOff = 10
  };

  /// @brief Enums for time slots
  ///
  enum Slot : uint8_t
  {
    Slot1 = 0,
    Slot2 = 1,
    Slot3 = 2,
    Slot4 = 3,
    Slot5 = 4,
    Slot6 = 5,
    Slot7 = 6,
    Slot8 = 7,
    SlotDate = 8,
    SlotTemperature = 9,
    SlotTimer = 10,
    SlotMenu = 11,
    SlotSet = 12,
    SlotDmx = 13,
    SlotCalculated = 14
  };


  /// @brief Enums for colors
  ///
  enum Color : uint8_t
  {
    Color0 = 0,
    Color1 = 1
  };


public:

  /// @brief Where settings will be written in FLASH
  ///
  static const uint32_t cSettingsFlashAddress;

  /// @brief Bits used in each settings class
  ///
  static const uint16_t cSettingData[];

  /// @brief Default constructor
  ///
  Settings();


  /// @brief Initialize settings
  ///
  void initialize();

  /// @brief Loads settings from FLASH
  /// @return true if success, false if failure & defaults were set
  ///
  bool loadFromFlash();

  /// @brief Saves settings to FLASH
  /// @return result of writeFlash()
  ///
  uint32_t saveToFlash();


  /// @brief Returns a setting
  /// @return true if setting is enabled, false otherwise
  ///
  bool getSetting(const uint8_t setting, const uint8_t item);

  /// @brief Sets a setting
  ///
  void setSetting(const uint8_t setting, const uint8_t item, const bool state);

  /// @brief Returns all settings
  /// @return value of requested setting
  ///
  uint16_t getRawSetting(const uint8_t setting);

  /// @brief Sets all settings
  ///
  void setRawSetting(const uint8_t setting, const uint16_t value);


  /// @brief Get a time value stored in the settings
  ///
  DateTime getTime(const Slot setting);
  DateTime getTime(const uint8_t setting);

  /// @brief Set a time value in the settings
  ///
  void setTime(const Slot setting, const DateTime time);
  void setTime(const uint8_t setting, const DateTime time);


  /// @brief Gets a time slot's color value
  ///
  RgbLed getColor(const Color color, const Slot slot, const bool setFadeDuration = false);
  RgbLed getColor(const uint8_t color, const uint8_t slot, const bool setFadeDuration = false);

  /// @brief Set a time slot's color values in the settings
  ///
  void setColors(const Slot slot, const RgbLed color0, const RgbLed color1);
  void setColors(const uint8_t slot, const RgbLed color0, const RgbLed color1);

  /// @brief Update the colors used when fading across time slots
  ///
  void refreshCalculatedColors();


private:

  /// @brief array of values for various settings data
  ///
  uint16_t _setting[Setting::DmxAddress + 1];

  /// @brief array of stored times for the alarms and/or color changes
  ///
  DateTime _time[Slot::Slot8 + 1];

  /// @brief two arrays of colors...one for '0' and one for '1'
  ///
  RgbLed _color[2][Slot::SlotCalculated + 1];

  /// @brief determines validity of Settings data after loading from FLASH
  ///
  uint32_t _crc;
};

}

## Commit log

2018-02-18 Modified PCBs to accommodate a 16mm buzzer element
    [kbxBinaryClock-MCU.v2.1.sch, kbxBinaryClock-MCU.v3.sch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]
2018-02-18 Added BoM, hw README, PCB tweaks
    [kbxBinaryClock-Display.v3.sch, kbxBinaryClock-MCU.v2.1.sch, kbxBinaryClock-MCU.v3.sch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]
2018-02-18 BoM fix
    [kbxBinaryClock.bom.csv]
2018-02-22 Status LED tweaks, performance tweaks
2018-03-01 Part numbering fix
    [kbxBinaryClock.bom.csv]
2018-03-03 Lots of clean-up and fixes
    [Hardware.cpp]
2018-03-03 Added disconnect on DS323x reset line
    [kbxBinaryClock-Peripherals.v2.1.sch, kbxBinaryClock-Peripherals.v3.sch, kbxBinaryClock.v2.1.kicad_pcb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]
2018-03-03 Updated gerbers
    [kbxBinaryClock.v2.1-B.Adhes.gbr, kbxBinaryClock.v2.1-B.Cu.gbr, kbxBinaryClock.v2.1-B.Fab.gbr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]
2018-03-09 Updated/added gerbers
    [kbxBinaryClock.v2.1-B.Adhes.gbr, kbxBinaryClock.v2.1-B.CrtYd.gbr, kbxBinaryClock.v2.1-B.Cu.gbr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]
2018-03-13 All sorts of tweaks/fixes/additions
    [DS1722.cpp, Hardware.cpp]
2018-03-18 SetTimeDateView can display AM/PM on status LED
2018-03-20 Updated Silkscreen for volume mode and added clearer pin 1 markings for ICs
    [kbxBinaryClock.v2.1-B.Adhes.gbr, kbxBinaryClock.v2.1-B.CrtYd.gbr, kbxBinaryClock.v2.1-B.Cu.gbr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]
2018-03-22 More color customizations, fixes, binaries
    [Hardware.cpp]
2018-03-23 Cleaned up temp sensor APIs
2018-03-31 Added MSOP footprint for temp sensor
    [kbxBinaryClock-Peripherals.v2.1.sch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]
2018-04-01 Updated slikscreen, minor tweaks
    [kbxBinaryClock.v2.1-B.Adhes.gbr, kbxBinaryClock.v2.1-B.CrtYd.gbr, kbxBinaryClock.v2.1-B.Cu.gbr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]
2018-04-03 Everything DMA and I2C works properly now
2018-04-10 Proper MCP9808 support, other fixes and tweaks
    [DS3231.cpp, Hardware.cpp, LM75.cpp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]
2018-05-28 Squashed a display bug, some other tweaks
    [Hardware.cpp]
2018-06-10 General clean-up, tweaks, and fixes
    [Hardware.cpp, Settings.h]
2018-06-10 BoM separation by hw version, markdown versions added
    [kbxBinaryClock.bom v2.csv, kbxBinaryClock.bom.csv, kbxBinaryClock.bom.v3.csv]
2018-06-10 BoM formatting fix
2018-06-10 BoM copy fix
2018-06-11 Attached CC-BY-SA to hardware
2018-06-11 Copy update regarding heat
2018-11-26 Initial v4 hw & sw commit
    [kbxBinaryClock-Display.v4.sch, kbxBinaryClock-MCU.v4.sch, kbxBinaryClock-Peripherals.v4.sch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]
2018-12-09 Various tweaks and fixes
    [DisplayManager.cpp, Hardware.cpp]
2019-01-03 Various fixes, improvements, and clean-up
    [DisplayManager.cpp]
2019-01-03 Updated for KiCad v5, updated silks
    [kbxBinaryClock-Display.v2.1-2018-12-13-23-08-22.sch, kbxBinaryClock-Display.v2.1-2018-12-13-23-09-19.sch, kbxBinaryClock-Display.v2.1.sch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]
2019-01-09 AlarmHandler reworked, date format added, other fixes
    [Settings.h]
2019-02-09 Clean-up of some DMA code for readability

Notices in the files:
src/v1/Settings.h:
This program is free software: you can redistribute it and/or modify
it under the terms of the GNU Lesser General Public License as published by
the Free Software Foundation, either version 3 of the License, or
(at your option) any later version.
